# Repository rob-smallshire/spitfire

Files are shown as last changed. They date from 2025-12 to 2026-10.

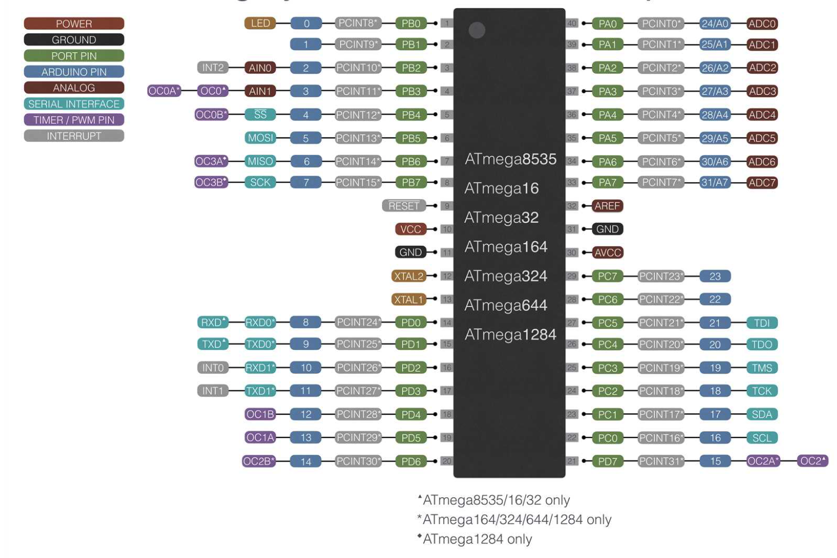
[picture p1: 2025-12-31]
docs/datasheets/atmega-1284p-pinout.png

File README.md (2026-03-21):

# SPItFIRE

**SPI + joystick FIRE button** - An analogue joystick and quadrature mouse adapter for the Acorn BBC Master Compact.

## Overview

The Acorn BBC Master Compact lacks the analogue-to-digital converter (ADC) hardware found in other BBC Micro models, making it incompatible with standard analogue joysticks. SPItFIRE bridges this gap by providing:

- **Analogue joystick support** via ADC sampling of potentiometer positions
- **Peripheral DE-9 port** for connecting a quadrature mouse (or other devices)
- **Keyboard matrix scanning** for joystick buttons

The system uses an ATMega1284p microcontroller as an SPI slave device. The BBC Master Compact's Mouse/Joystick port (an exposed 6522 VIA) communicates with the microcontroller via a bit-banged SPI protocol.

## Architecture

```
                               Host DE-9
┌─────────────────────┐         SPI          ┌──────────────────────┐
│  BBC Master Compact │◄────────────────────►│     ATMega1284p      │
│                     │   (bit-banged on     │                      │
│  6522 VIA Port      │    User VIA Port B)  │  ┌────────────────┐  │
└─────────────────────┘                      │  │ ADC: Joystick  │  │
                                             │  │ GPIO: Buttons  │  │
                                             │  │ GPIO: Mouse    │  │
                                             │  └────────────────┘  │
                                             └──────────────────────┘
                                                      │
                       ┌──────────────────────┬───────┴───────┐
                       ▼                      ▼               ▼
                 ┌──────────┐          ┌──────────┐   ┌──────────────┐
                 │ Joystick │          │  Keypad  │   │ Peripheral   │
                 │ (Analog) │          │  Matrix  │   │    DE-9      │
                 │  DA-15   │          │          │   │ Mouse/Serial │
                 └──────────┘          └──────────┘   └──────────────┘
```

## Repository Structure

```
spitfire/
├── firmware/           ATMega1284p C++ firmware (SPI slave)
│   ├── src/            Source files
│   ├── include/        Header files
│   ├── cmake/          CMake toolchain files
│   ├── CMakeLists.txt  Build configuration
│   └── CMakePresets.json
├── rom/                BBC Micro 6502 assembly ROM driver
│   └── src/            BeebAsm source files
├── hardware/           KiCAD hardware designs
│   └── spitfire/       Main schematic and PCB
└── docs/               Documentation
    └── protocol.md     SPI protocol specification
```

## Building

### Firmware (ATMega1284p)

Requirements:
- CMake 3.20+
- avr-gcc toolchain
- avrdude (for programming)

```bash
cd firmware
cmake --preset release
cmake --build --preset release
cmake --build --preset release --target upload
```

### ROM (BBC Micro)

Requirements:
- BeebAsm assembler

```bash
cd rom
make
```

## Hardware

The hardware design is created in KiCAD. See the `hardware/` directory for schematics and PCB layouts.

### Connectors

SPItFIRE has two DE-9 connectors:

- **Host DE-9**: Connects to BBC Master Compact's Mouse/Joystick port (exposes 6522 VIA). Carries SPI bus signals and device selection.
- **Peripheral DE-9**: Directly connects input devices to SPItFIRE. Directly accepts quadrature mice, switched joysticks, or serial devices. Connected to AVR Port D.

### Additional Connections

- **Joystick Inputs**: Two DA-15 ports for analogue joysticks (directly via ADC channels)

## Protocol

The BBC Micro bit-bangs an SPI protocol on the VIA port to:
- Configure the adapter
- Request joystick position data (X/Y axes)
- Request mouse velocity data
- Read button states

See [docs/protocol.md](docs/protocol.md) for the full protocol specification.

## License

This project is licensed under the GNU General Public License v3.0 - see the [LICENSE](LICENSE) file for details.

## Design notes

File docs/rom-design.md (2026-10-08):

# SPItFIRE ROM Design

This document describes the proposed architecture for the BBC Micro Sideways
ROM that drives the SPItFIRE adapter. It is a working proposal and will
evolve as we implement and learn.

## Goals

- Provide standard BBC Micro APIs (ADVAL, INKEY, OSWORD &40, *MOUSE, etc.)
  so existing software works without modification.
- Be modular: support optional features matching the hardware actually
  plugged into the SPItFIRE.
- Share a common SPI driver across all modules.
- Compatible with the BBC sideways ROM ecosystem and existing conventions.

## Architecture Overview

```
┌─────────────────────────────────────────┐
│           SPItFIRE ROM Image            │
├─────────────────────────────────────────┤
│  ROM Header (one per ROM)               │
│    - JMP to Service dispatcher          │
│    - Standard BBC Micro ROM type/title  │
│    - Copyright, version                 │
├─────────────────────────────────────────┤
│  Service Dispatcher                     │
│    - Offers each service call to each   │
│      enabled module in turn             │
│    - Standard claim/pass conventions    │
├─────────────────────────────────────────┤
│  Module: SPI Core (always present)      │
│    - Bit-bang SPI routines              │
│    - Turbo (shift register) routines    │
│    - 74HC138 device selection           │
│    - Shared zero-page workspace         │
├─────────────────────────────────────────┤
│  Module: Mouse (optional)               │
│    - Hooks BYTEV, EVENTV                │
│    - Uses SPI Core                      │
│    - Provides ADVAL 7-9, OSWORD &40     │
│    - *MOUSE [ON|OFF|TYPE]               │
├─────────────────────────────────────────┤
│  Module: Joystick (optional)            │
│    - Hooks BYTEV                        │
│    - Uses SPI Core                      │
│    - Provides ADVAL 1-4 (or extended)   │
├─────────────────────────────────────────┤
│  Module: RTC (optional)                 │
│    - Service call &08: OSWORD &0E/&0F   │
│    - So *TIME and TIME$ read the DS3234 │
└─────────────────────────────────────────┘
```

The SD card filing system is not part of this ROM: it is MMFS, built
with a SPItFIRE device driver, in a ROM of its own. See
[SD Card Filing System](#sd-card-filing-system-separate-mmfs-rom).

## Reference: JGH's Module System

J.G. Harston's relocatable module system at
[mdfs.net](https://mdfs.net/Software/BBC/Modules/) provides useful precedent:

- **MouseROM** - reference for mouse API conventions (we'll rewrite the
  hardware-facing end completely; the MOS-facing API is identical).
- **SoftRTC2** - reference for RTC integration with system clock.
- **SMLib** - relocatable module framework (we may adopt later, not
  required for first version).
- **MMFS** - existing MMC filing system. Standard MMFS ties SS to
  ground, so we added a SPItFIRE device driver to it (see below).

We should not be wilfully different on the MOS-facing side. Standard
APIs and command syntax should match the existing BBC ecosystem.

## Module: SPI Core

Always present. Provides shared low-level routines used by all other
modules.

### Responsibilities
- Initialise User VIA for SPI bit-bang and shift register modes
- Bit-bang SPI transfer routine (~4100 bytes/sec)
- Turbo SPI transfer routine using VIA shift register (~7400 bytes/sec)
- 74HC138 device selection (constants for each device assignment)
- Common workspace allocation

### Public Routines
| Routine | Inputs | Outputs | Description |
|---|---|---|---|
| `init_via` | - | - | One-time VIA setup |
| `select_device` | A=device | - | Set SCK to the device's idle level, then select it via 74HC138 |
| `deselect_device` | - | - | Deselect (Y7 = no device) |
| `spi_transfer` | A=byte | A=received | Bit-bang transfer |
| `spi_turbo_read` | - | A=received | Fast read using shift register |

### Per-device SPI mode
The 6522 shift register samples MISO on the rising edge of SCK (CB1), so
every device must present data that is stable at the rising edge:

| Device | SPI mode | SCK idle level when selected |
|---|---|---|
| SPItFIRE AVR | 0 | Low |
| DS3234 RTC | 3 (it picks CPOL from SCK at CS falling) | High |
| SD card | 3 (as MMFS) | High |

`select_device` must therefore set SCK to the device's idle level
*before* asserting chip select, and the transfer routines must keep that
idle level between bytes. Verified with SPIRTC on the Rev 1 board.

### Device Assignments
See [spi-interface.md](spi-interface.md) and
[peripheral-pinouts.md](peripheral-pinouts.md).

| Output | Device | Constant |
|---|---|---|
| Y0 | Unassigned (unconnected on Rev 1; spare header on Rev 2) | |
| Y1 | SPItFIRE AVR | `DEV_SPITFIRE` |
| Y2 | SD card (J4, Adafruit microSD breakout) | `DEV_SD` |
| Y3 | RTC (J5, SparkFun DeadOn DS3234) | `DEV_RTC` |
| Y4-Y6 | Unassigned (spare headers J6-J8) | |
| Y7 | None (deselect): the Compact's idle state, see [spi-interface.md](spi-interface.md) | `DEV_NONE` |

## The `*SPITFIRE` Command Namespace

Standard commands like `*MOUSE`, `*TIME`, `*DATE` are kept in their
established namespaces for ecosystem compatibility. SPItFIRE-specific
configuration and extensions live under a `*SPITFIRE` command with a
subcommand structure that mirrors the module hierarchy.

### Rationale
- Avoids polluting the global `*` command namespace
- Groups all SPItFIRE-specific functionality under one prefix
- The hierarchy maps naturally to the modular ROM design
- Tab-style discoverability via `*HELP SPITFIRE`

### Proposed Subcommand Structure
This is a working sketch, not a final design:

| Command | Description |
|---|---|
| `*SPITFIRE` | Show ROM version and active modules |
| `*SPITFIRE INFO` | Show hardware status, AVR firmware version, attached devices |
| `*SPITFIRE HELP [topic]` | Show help (optionally for a subsystem) |
| `*SPITFIRE MOUSE ON\|OFF` | Alias for `*MOUSE ON\|OFF` |
| `*SPITFIRE MOUSE TYPE AMX\|AMIGA\|ATARI` | Select pinout (AVR mode) |
| `*SPITFIRE MOUSE SENSITIVITY sx [,sy]` | Set per-axis sensitivity (2^sx GU/pulse) |
| `*SPITFIRE MOUSE INFO` | Report current state, pulse counts, mode |
| `*SPITFIRE JOYSTICK A 14B\|3B\|3B-TWIN\|...` | Configure joystick port A |
| `*SPITFIRE JOYSTICK B ...` | Configure joystick port B |
| `*SPITFIRE JOYSTICK INFO` | Report joystick state |
| `*SPITFIRE RTC INFO` | Show RTC status (oscillator stop flag, temperature, aging) |
| `*SPITFIRE SD INFO` | Show SD card status |

### Implementation Note
Each module registers its own `*SPITFIRE <name>` subcommand handler.
The top-level `*SPITFIRE` parser dispatches to the appropriate module
based on the first word after `*SPITFIRE`. A module's subcommand
handler need not be present if the module is excluded from the build.

## Module: Mouse

Replicates the JGH/AMX mouse API. Polls the SPItFIRE AVR via SPI on a
periodic timer event instead of using CB1/CB2 IRQs.

### MOS-facing API (drop-in compatible)
| Call | Description |
|---|---|
| `*MOUSE ON` | Enable mouse |
| `*MOUSE OFF` | Disable mouse |
| `*HELP MOUSE` | Show help text |
| `ADVAL(5)` | Mouse X boundary (max X) |
| `ADVAL(6)` | Mouse Y boundary (max Y) |
| `ADVAL(7)` | X position (graphics units, 0-1279) |
| `ADVAL(8)` | Y position (graphics units, 0-1023) |
| `ADVAL(9)` | Buttons - active HIGH (b0=Left, b1=Middle, b2=Right) |
| `INKEY-10` | Left button (-1 if pressed) |
| `INKEY-11` | Middle button |
| `INKEY-12` | Right button |
| `OSWORD &40` | Full mouse state to user buffer (see below) |

### OSWORD &40 buffer format
7 bytes returned at the address pointed to by XY:

| Offset | Content |
|---|---|
| +0 | LSB of X co-ordinate |
| +1 | MSB of X co-ordinate |
| +2 | LSB of Y co-ordinate |
| +3 | MSB of Y co-ordinate |
| +4 | Text X co-ordinate (0-19 / 0-39 / 0-79 depending on MODE) |
| +5 | Text Y co-ordinate (0-31) |
| +6 | Buttons - format `cme00000`, **active LOW** (bit reset = pressed) |

Note the dual button conventions:
- **ADVAL(9)**: active-high in bits 0-2, order Left/Middle/Right
- **OSWORD &40 byte 6**: active-low in bits 5-7, order Execute/Move/Cancel
  (= Left/Middle/Right) - this matches the raw IORB layout on a BBC/Master
  with buttons on PB5-PB7

### Coordinate Systems

The mouse driver returns positions in two coordinate systems:

| Coordinate | Units | Range | Origin |
|---|---|---|---|
| Graphics X | Graphics units (GU) | 0-1279 | Bottom-left |
| Graphics Y | Graphics units (GU) | 0-1023 | Bottom-left |
| Text X | Character cells | 0-19 (MODE 7), 0-39 (MODE 1/4/5), 0-79 (MODE 0/3/6) | Top-left |
| Text Y | Character cells | 0-24 (MODE 3/6), 0-31 (others) | Top-left |

Important conventions inherited from BBC Micro / Acorn MOS:

- **Graphics origin is bottom-left**: Y=0 at the bottom of the screen,
  Y increases upward. This is opposite to many other systems (notably
  modern displays, X11, Windows, etc. which place origin at top-left).
- **Text origin is top-left**: text Y=0 at the top, increasing downward.
- **Mouse Y increment direction**: when the mouse is moved upward (away
  from the user), graphics Y increases, matching BBC graphics convention.
- The graphics coordinate system is independent of screen MODE - it is
  always 1280x1024 GU regardless of the actual pixel resolution. The MOS
  scales graphics commands appropriately.

The text coordinate ranges depend on the current screen MODE:

| MODE | Text Width | Text Height |
|---|---|---|
| 0 | 80 columns | 32 rows |
| 1 | 40 columns | 32 rows |
| 2 | 20 columns | 32 rows |
| 3 | 80 columns | 25 rows |
| 4 | 40 columns | 32 rows |
| 5 | 20 columns | 32 rows |
| 6 | 40 columns | 25 rows |
| 7 | 40 columns | 25 rows (teletext) |

### Standard commands not directly implemented
The original AMX ROM provided pointer/icon/window helper commands and
a `*SENSITIVITY sx [,sy]` command. We do not reimplement these in
`*MOUSE` namespace; instead:
- Pointer/icon/window helpers are out of scope (they are GUI helpers,
  not core mouse driver functionality)
- Sensitivity adjustment is exposed via `*SPITFIRE MOUSE SENSITIVITY`
  (see SPItFIRE namespace below)

References:
- [BeebWiki OSBYTE &80](https://beebwiki.mdfs.net/OSBYTE_%2680) - ADVAL details
- AMX Mouse User Guide: `docs/datasheets/AMX_MouseUG.pdf` chapter 5
- ADVAL(9) bit ordering: BeebWiki says "b0=Left, b1=Middle, b2=Right";
  JGH's `%rml` notation describes the same bits (binary digit positions:
  r is highest, m middle, l lowest = b2,b1,b0).
- BeebWiki notes: "Most mouse drivers do not implement calls 5, 6 and 9."
  We should implement all of them for completeness since the AVR provides
  the data cheaply.

### SPItFIRE-specific extensions
SPItFIRE-specific configuration is exposed via the `*SPITFIRE` namespace
(see above) rather than extending the standard `*MOUSE` command:

| Command | Description |
|---|---|
| `*SPITFIRE MOUSE TYPE AMX` | Select AMX/Compact pinout (AVR mode 0xF1) |
| `*SPITFIRE MOUSE TYPE AMIGA` | Select Amiga pinout (AVR mode 0xF2) |
| `*SPITFIRE MOUSE TYPE ATARI` | Select Atari pinout (AVR mode 0xF3) |
| `*SPITFIRE MOUSE SENSITIVITY sx [,sy]` | Set per-axis sensitivity (2^sx GU/pulse) |
| `*SPITFIRE MOUSE INFO` | Report state, mode, pulse counts |

### Workspace (drop-in compatible with JGH)
| Address | Use |
|---|-----|
| `&DA5` | Status (b7=enabled, b3-b0=type/speed) |
| `&DA6-&DA9` | Position (X.lo, X.hi, Y.lo, Y.hi) |
| `&DAA` | Flag |
| `&D9B-&D9D` | Saved BYTEV (3 bytes) |
| `&DAE-&DB0` | Extended BYTEV (XBYTEV) |

### Polling Mechanism
- Hook EVENTV
- Use Event 4 (vsync) for 50 Hz polling, OR
- Use Event 5 with OSWORD &03 interval timer for 100 Hz
- 50 Hz vsync is simpler and likely sufficient
- Each event: select SPItFIRE, send 0x30/0x31/0x32 commands, deselect,
  accumulate dX/dY into position, store buttons

### Button Format Conversion
The AVR returns buttons as `b0=L, b1=R, b2=M`. ADVAL(9) requires `%rml`
which is `b0=L, b1=M, b2=R`. The driver swaps bits 1 and 2.

### Position Bounds
- Initial position: X=&280 (640), Y=&200 (512)
- Increment of 4 graphics units per pulse (matches BBC convention)
- Bound to screen extent via OSBYTE &A0 (read VDU vars)

## Module: Joystick

Provides analogue joystick support via SPItFIRE.

### MOS-facing API
| Call | Description |
|---|---|
| `ADVAL(1)` | Channel 0 X (joystick A) |
| `ADVAL(2)` | Channel 0 Y |
| `ADVAL(3)` | Channel 1 X (joystick B) |
| `ADVAL(4)` | Channel 1 Y |
| `OSBYTE &80` with X=0 | Last channel converted |
| Various INKEY values | Fire buttons |

### SPItFIRE-specific commands
TBD - configuration of joystick types (3B Single, 3B Twin, 14B keypad, etc.)
matching the existing AVR firmware test interface.

### Polling Mechanism
- ADC values change slowly (analogue position)
- Could poll on demand (each ADVAL call) or periodically
- Periodic polling at 25 Hz via vsync should be sufficient

## Module: RTC

Makes the DS3234 on J5 (decoder output Y3, `DEV_RTC`) the machine's
clock, so `*TIME`, BASIC's `TIME$` and anything else using OSWORD &0E
(read clock) and &0F (write clock) see real time. The Master 128 had a
clock; the Compact's was removed to save cost, and MOS 5.10 only returns
a fixed default.

### Findings on the Compact
Probed with TIMEPROBE (`beeb/spitest/src/timeprobe.asm`), which calls
OSWORD &0E with all ROMs, with every ROM hidden, and with each ROM on its
own. Results on our Compact (MOS 5.10, ANFS 4.25 in slot 3):

| Call | All ROMs (ANFS answers) | MOS only |
|---|---|---|
| &0E,0 string | ` ,71 Oct 1994.23:25:49` | `Fri,31 Dec 1999.23:59:59` |
| &0E,1 BCD | `94 10 71 00 23 25 49` | `99 12 31 06 23 59 59` |
| &0E,2 of `26 10 07 04 12 34 56` | - | `Wed,07 Oct 1926.12:34:56` |
| &0E,2 of `26 10 07 00 12 34 56` | - | ` ,07 Oct 1926.12:34:56` |

- **MOS 5.10 offers OSWORD &0E to sideways ROMs** with service call &08
  (unrecognised OSWORD). ANFS 4.25 answers subcalls 0 and 1 by asking the
  Econet file server. With no ROM answering, the MOS returns its default,
  Fri 31 Dec 1999 23:59:59. (The Master 128 MOS handles these calls
  itself and never offers them to ROMs; a Master add-on would have to
  claim WORDV instead.)
- **MOS subcall 2 always prints the century as 19**, so 2026 comes out
  as 1926. A weekday of 0 prints as three spaces. The MOS offers subcall
  2 to ROMs first, though: with the SPItFIRE ROM loaded, TIMEPROBE's
  all-ROMs conversion of year &26 gives 2026.
- Every string is 25 bytes, `Ddd,dd Mon yyyy.hh:mm:ss` plus CR.
- **ANFS 4.25 mis-decodes file server dates after 1996.** The server puts
  the high year bits in bits 5-7 of the day byte, and ANFS passes the
  whole byte on as the date. `71` with year `94` decodes as
  day = 71 AND 31 = 7, year = (71 AND &E0)/2 + 94 + 1900 = 2026: the
  correct date, 7 Oct 2026. The file server is right; ANFS is wrong.
  ANFS also returns weekday 0 ("unknown"). This is what `*TIME` showed
  before SPItFIRE.

### How the module hooks in
- **Service call &08.** On entry the OSWORD number is at &EF and the
  parameter block address at &F0/&F1. Handle OSWORD &0E and &0F, return
  A=0 to claim, and preserve X and Y. Anything not handled returns with
  A unchanged, so other ROMs (ANFS especially) still see it.
- **ROM slot above ANFS.** Service calls are offered from the highest slot
  down, so the SPItFIRE ROM must sit in a higher slot than ANFS (slot 3
  on our Compact) to answer before it.
- **If no DS3234 is fitted, or the clock is not valid**, pass the call
  on, so the machine falls back to ANFS or the MOS default.
  - *Presence* (all calls): MISO floats when nothing drives it (Rev 1
    has no pull-up; see Rev 2 erratum 2 in
    [rev1-bringup.md](rev1-bringup.md)), so a read alone cannot show that
    a DS3234 answered. The module writes the complement of the SRAM
    address register (18h, no side effects) and reads it back, then
    restores it. A floating line cannot echo the value.
  - *Validity* (reads only): the oscillator stop flag must be clear and
    every time field valid BCD within its range. The ranges also cover
    the bits that always read 0, and reject 12-hour mode. Writes do not
    require a valid stored time, so `*TIME` can always repair the clock.

### Calls to implement

| Call | Data | Notes |
|---|---|---|
| &0E,0 | Return `Ddd,dd Mon yyyy.hh:mm:ss` + CR (25 bytes) | Build the string ourselves with the real century; do not use MOS subcall 2 |
| &0E,1 | Return 7 BCD bytes: year, month, date, weekday, hours, minutes, seconds | Weekday &01-&07 = Sun-Sat, as SPISETTIME writes it to the DS3234 |
| &0E,2 | Convert 7 BCD bytes at XY+1 to a string | MOS 5.10 offers it to ROMs before converting it itself, so claiming it fixes the century for every caller. Year &00-&79 = 20xx, &80-&99 = 19xx |
| &0F,8 | `hh:mm:ss` | Set the time, leave the date |
| &0F,15 | `Ddd,dd Mon yyyy` | Set the date, leave the time |
| &0F,24 | `Ddd,dd Mon yyyy.hh:mm:ss` | Set both |

Leave alone: &0E subcalls 3 and 4, which ANFS uses for the file server's
time (and other ROMs use inconsistently), and every other subcall or
length. The string field positions are fixed: programs parse `TIME$`.

### Conventions (from the Stardot discussions)
- **OSWORD calls never raise errors.** Invalid OSWORD &0F data is
  ignored (or passed on). Errors belong to `*` commands.
- **&A8-&AF belong to `*` commands.** An OSWORD handler that uses them
  as workspace must save and restore them (e.g. on the stack).
- **Return the real four-digit year** in subcall 0. Copying the
  Master's 19xx is not required by the specification.
- The 6502's V flag is not valid in decimal mode, which matters for any
  BCD arithmetic (e.g. a future timezone offset).

### Setting the clock
`*TIME <string>` and `TIME$=` set the clock through OSWORD &0F, so
nothing extra is needed beyond the &0F handler: verified on the Compact,
where MOS 5.10's `*TIME` passes its argument to OSWORD &0F. Any of the
three forms (time, date, or both) works from either.

The handler ignores the weekday name and computes the weekday from the
date (Sakamoto's method, reduced to 8 bits for 2000-2199). It accepts
years 2000-2199, the range of the DS3234's century bit, checks the date
against the length of the month (2100 is not a leap year), and passes
anything invalid on. A successful write clears the oscillator stop flag.

### Possible later extensions
Time & Config defines further subcalls: &0E,5 for century and timezone,
&0E,6 for when the clock was last set, &0F lengths for synchronising to
the second and adjusting drift. None is a settled standard; leave them
out of the first version.

### Not to be confused with the system clock
OSWORD 1/2 (`TIME` in BASIC) is a centisecond counter, unrelated to the
calendar clock; the earlier idea of writing the RTC into &028D-&028F is
wrong.

## SD Card Filing System (separate MMFS ROM)

**Decision:** the SD card is served by MMFS in its own ROM, not by a
module of the SPItFIRE ROM. MMFS gets a SPItFIRE device driver and
nothing else, so the change stays small enough to offer upstream.

- Fork: <https://github.com/rob-smallshire/MMFS>, branch `spitfire`
  (upstream <https://github.com/hoglet67/MMFS>). Local clone at
  `~/Code/MMFS` with `origin` = the fork, `upstream` = hoglet67.
- Driver: `MMC_Spitfire.asm`, MMFS device `S`. Based on the non-turbo
  User Port driver (`MMC_UserPort.asm`, device `U`).
- Build: the Master build (`top_MAMMFS.asm`) is the one for the Compact.
  MMFS2 (FAT32 card with `.ssd`/`.dsd` files) is the variant in use.
- Tested on the Rev 1 board: `*DCAT`, `*DIN` and running games from a
  FAT32 SDHC card. Writes are not yet tested on hardware.

### How the driver differs from the User Port driver
- PB0-PB4 are outputs, and every write to IORB carries the SD card's
  select code (Y2, `&08`), so the card stays selected throughout a
  transaction.
- The bit-banged byte write keeps PB2-PB4 constant. The User Port
  version lets unsent data bits ripple across PB2-PB7, which on our
  board would switch the decoder between devices mid-byte. The rewrite
  is about 1.6x slower, but writes are only bit-banged commands and data
  blocks; bulk reads use shift register mode 2 and run at the original
  speed.
- `MMC_DEVICE_RESET` (called from `MMC_BEGIN1` at the start of every
  transaction) raises SCK with no device selected, then selects the card
  (SPI mode 3).
- `MMC_DEVICE_DESELECT` selects Y7 (no device) and sends 8 clocks so the card
  releases MISO. It is called from `ResetLEDS`, which MMFS calls at the
  end of every card operation and when reporting any error, and from
  `MMC_END`. `MMC_END` alone was not enough: `MMC_BEGIN`/`MMC_END`
  bracket a zero page save, not a card operation (`MMC_BEGIN2` calls
  both at once, and the reads follow), so the card was left selected
  after booting with MMFS2 active and after `*DCAT`. Verified on the
  Compact: the decoder now rests on no device and the SD card's LED is off
  except while loading.
- The TurboMMC mode 6 write path is not used: it relies on external
  buffers switched by PB2-PB4, which on our board are decoder inputs.

### ROM space
The Master MMFS2 build leaves about 3.4 KB free, which could only just
hold the rest of the SPItFIRE modules (estimated 2.3-3.7 KB) with no
margin. Keeping them separate also keeps the MMFS fork upstreamable.
The cost is a second ROM slot; at least one Compact socket takes a 32K
ROM spanning two 16K sideways slots, so this is not a constraint in
practice.

### Bus access between the two ROMs (to be designed)
The mouse (and possibly joystick) module will poll the AVR from an
interrupt, and that poll must not disturb an MMFS transaction in
progress. Points to settle:

- A "bus busy" flag at an address both ROMs agree on. The
  interrupt-time poll must *skip* when the flag is set; it must never
  wait, because MMFS cannot proceed until the interrupt returns.
- Where MMFS sets and clears it: not `MMC_BEGIN1`/`MMC_END`, which do
  not bracket card operations (see above). `SetLEDS` and `ResetLEDS`
  bracket nearly all of them, and `ResetLEDS` also runs on every error
  report, so the flag would not be left set by a BRK. Exceptions to
  cover: `MMC_GetCIDCRC` (card ID check) reads the card without
  `SetLEDS`.
- Outside a transaction, a poll changes PB2-PB4, the SCK idle level and
  possibly the shift register mode. Either the poll restores what it
  found, or MMFS reselects at the start of every transaction. It already
  does the latter in `MMC_DEVICE_RESET`.

## Build/Configuration System

### Directory Structure
```
beeb/spitfire-rom/
├── src/
│   ├── header.asm          # ROM header, service dispatcher
│   ├── spi_core.asm        # Shared SPI driver
│   ├── mod_mouse.asm       # Mouse module
│   ├── mod_joystick.asm    # Joystick module
│   ├── mod_rtc.asm         # RTC module
│   └── workspace.asm       # Shared workspace allocation
├── configs/
│   ├── full.asm            # All modules
│   ├── mouse_only.asm      # SPI core + mouse only
│   ├── input.asm           # SPI core + mouse + joystick
│   └── clock.asm           # SPI core + RTC
└── Makefile                # Build rule per config
```

### Configuration Files
Each `configs/<name>.asm` is a thin wrapper:
```asm
ROM_TITLE = "SPItFIRE Mouse"
ROM_VERSION = "0.01"

INCLUDE "../src/header.asm"
INCLUDE "../src/workspace.asm"
INCLUDE "../src/spi_core.asm"
INCLUDE "../src/mod_mouse.asm"
INCLUDE "../src/footer.asm"

SAVE "SPITFIRE", start, end
```

### Module Conventions
Each module file should:
- Define its own labels in a unique prefix (e.g. `mouse_init`)
- Provide a service entry point `<module>_service`
- Declare its workspace requirements
- Document its dependencies (e.g. requires SPI Core)

### Service Dispatch Pattern
Header's service dispatcher offers the call to each module in turn:
```asm
.Service
    JSR mouse_service
    BEQ exit_service           ; A=0 means claimed
    JSR joystick_service
    BEQ exit_service
    JSR rtc_service
    BEQ exit_service
    ; ... unclaimed, exit normally
.exit_service
    RTS
```

Modules return claim status in A:
- A=0: claimed (stop dispatch)
- A unchanged: not handled (continue dispatch)

## Open Questions

1. **Single ROM vs multiple ROMs?**
   - Single 16K ROM with all modules: consumes one bank slot, simple to load
   - Multiple ROMs: better separation, but uses multiple bank slots
   - **Decision:** Two ROMs. The SPItFIRE ROM holds the SPI core, mouse,
     joystick and RTC modules, configurable at build time. The SD card
     filing system is a separate MMFS ROM (see
     [SD Card Filing System](#sd-card-filing-system-separate-mmfs-rom)).

2. **Relocation support?**
   - JGH's SMLib provides full relocatability
   - Not needed if we always build for &8000
   - **Initial preference:** Build for fixed address, add relocation later if needed

3. **Module enable/disable at runtime?**
   - User could disable modules with `*CONFIG`-style commands
   - More flexible but more complex
   - **Initial preference:** Build-time configuration only

4. **MMFS_Spitfire vs adopting an existing variant?**
   - Could fork existing MMFS source
   - Or implement minimal MMC layer for our hardware
   - **Decision:** Forked MMFS and added a device driver
     (`MMC_Spitfire.asm`, device `S`); working on the Rev 1 board

5. **RTC chip selection?**
   - DS3231 is popular and accurate (built-in TCXO)
   - DS3234 is the SPI variant of DS3231
   - **Decision:** DS3234 (SparkFun DeadOn breakout on J5); proven on the
     Rev 1 board by SPIRTC and SPISETTIME

## Implementation Plan (Proposed Order)

The RTC hardware is proven and its MOS interface is now understood, so
the RTC module comes first and brings the ROM skeleton with it:

1. **RTC module** - ROM header, service dispatcher, SPI core, OSWORD &0E
   and &0F (done, working on the Compact)
2. **Mouse module** - first input feature, hardware proven
3. **Joystick module** - reuse AVR firmware joystick code path
4. **Single-config build first** - all modules in one ROM, configurable later
5. **SD card** - done, as a separate MMFS ROM; still to do is the bus
   access protocol shared with the mouse module

## References

- [BeebWiki OSBYTE &80](https://beebwiki.mdfs.net/OSBYTE_%2680) - ADVAL details
- AMX Mouse User Guide: `docs/datasheets/AMX_MouseUG.pdf`
  ([source](https://chrisacorns.computinghistory.org.uk/docs/AMX/AMX_MouseUG.pdf))
- [JGH's relocatable modules](https://mdfs.net/Software/BBC/Modules/)
- [BeebWiki OSWORD &0E](https://beebwiki.mdfs.net/OSWORD_%260E) and
  [OSWORD &0F](https://beebwiki.mdfs.net/OSWORD_%260F) - clock calls,
  per-MOS behaviour, the ANFS date fix
- Stardot: [OSWORD 14 & 15 numbers](https://stardot.org.uk/forums/viewtopic.php?t=28743)
  and [Time & Config](https://stardot.org.uk/forums/viewtopic.php?t=30412)
  (Barney Hilken's RTC board; ROM source at
  <https://codeberg.org/Barneyntd/Time-Config.>)
- [JGH's MouseROM source](https://mdfs.net/Software/CommandSrc/Mouse/ROMMouse.src)
- [MDFS BBC Mouse documentation](https://mdfs.net/Info/Comp/BBC/Mouse/)
- Internal: [protocol.md](protocol.md) - SPI command set
- Internal: [spi-interface.md](spi-interface.md) - hardware layer
- Internal: [peripheral-pinouts.md](peripheral-pinouts.md) - device pinouts
- Internal: [mouse-trackball-peripheral.md](mouse-trackball-peripheral.md) - mouse details

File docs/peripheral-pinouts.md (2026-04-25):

# Peripheral DE-9 Pinouts

The SPItFIRE has a **male DE-9 Peripheral port** to support connection of the following devices:

* Master Compact Mouse (e.g. Prodest PC128S DigiMouse) - three button
* Master Compact/Atari Switched Joystick
* Amiga Mouse - three button
* Atari ST Mouse - two button (some three-button variants exist)
* Microsoft Bus Mouse - passive, unpowered (e.g. green-eyed mouse)
* TTL Serial port (e.g. StarTech IC232TTL TTL-to-RS232 adapter)

Port D of the AVR is connected to the Peripheral DE-9 and configured under software control to support these different device classes.

## AVR Port D Mapping

| DE-9 Pin | AVR Pin | Function | Notes |
|---|---|---|---|
| 1 | PD0 | RXD0 / GPIO | UART RX for IC232TTL; GPIO for mice/joystick |
| 2 | PD1 | TXD0 / GPIO | UART TX for IC232TTL; GPIO for mice/joystick |
| 3 | PD2 | GPIO | |
| 4 | PD3 | GPIO | |
| 5 | PD4 | GPIO | |
| 6 | PD5 | GPIO | |
| 7 | — | +5V | Hardwired, no AVR pin |
| 8 | — | GND | Hardwired, no AVR pin |
| 9 | PD6 | GPIO | |
| LED | PD7 | GPIO | Status LED, active on prototype |

The UART pins (PD0/PD1) are constrained by AVR hardware to map to Peripheral DE-9 pins 1/2, which conveniently aligns with the IC232TTL's RXD/TXD pins. For mouse and joystick modes, PD0/PD1 are reconfigured as standard GPIO inputs.

## Pinout Table

| Pin | AVR Pin | Compact Mouse | Joystick | Amiga Mouse | Atari Mouse | MS Bus Mouse | IC232TTL |
|-----|---|---|---|---|---|---|---|
| 1 | PD0 | XB | Up | YB | XB | NC | RXD |
| 2 | PD1 | Right Btn | Down | XA | XA | XA | TXD |
| 3 | PD2 | Middle Btn | Left | YA | YA | XB | NC |
| 4 | PD3 | YB | Right | XB | YB | YA | NC |
| 5 | PD4 | XA | NC | Middle Btn  | NC | YB | 0V |
| 6 | PD5 | Left Btn | Fire | Left Btn | Left Btn | Button 1 | NC* |
| 7 | — | +5V | NC | +5V | +5V | (B3)* | NC |
| 8 | — | 0V | 0V | 0V | 0V | Button 2 | NC |
| 9 | PD6 | YA | NC | Right Btn | Right Btn | 0V | NC |

**Notes:**
- NC* = Pin 6 on IC232TTL is a 5V *output* (device powered from RS232 side). Configure as Hi-Z.
- (B3)* = Bus mouse interface cards support Button 3 on pin 7, but SPItFIRE hardwires pin 7 to +5V for mouse/joystick compatibility. Third button not supported on bus mouse.
- Quadrature signals use standard notation: XA/XB for horizontal axis, YA/YB for vertical axis.
- Acorn documentation uses alternate naming: Xaxis=XA, Xdir=XB, Yaxis=YA, Ydir=YB.
- All button signals are active-low (directly connect to ground when pressed).

## Quadrature Signal Convention

All quadrature mice use the same encoding, only the pinout differs:

```
Movement right/down: (0,0) → (1,0) → (1,1) → (0,1) → (0,0)
Movement left/up:    (0,0) → (0,1) → (1,1) → (1,0) → (0,0)

When A leads B by 90°: positive direction (right/down)
When B leads A by 90°: negative direction (left/up)
```

## Gender Changer Requirements

The SPItFIRE Peripheral port is **male DE-9**. Standard mice and joysticks have female DE-9 plugs and connect directly. The following devices have male DE-9 plugs and require a **female-to-female gender changer**:

| Device | Connector | Gender Changer Required  |
|---|---|---|
| Compact Mouse | Female DE-9 | No - direct connection |
| Amiga Mouse | Female DE-9 | No - direct connection |
| Atari Mouse | Female DE-9 | No - direct connection |
| Atari/Compact Joystick | Female DE-9 | No - direct connection |
| Microsoft Bus Mouse | Male DE-9 | **Yes - F-F adapter** |
| StarTech IC232TTL | Male DE-9 | **Yes - F-F adapter** |

## Device-Specific Notes

### Master Compact Mouse

The Compact mouse pinout matches the BBC Master Compact's Mouse/Joystick port directly. The quadrature signals are on pins 1, 4, 5, 9 with buttons on pins 2, 3, 6.

Reference: [mdfs.net BBC Mouse](https://mdfs.net/Info/Comp/BBC/Mouse/)

### Amiga Mouse

The Amiga uses V-pulse/VQ-pulse (vertical) and H-pulse/HQ-pulse (horizontal) naming:
- V-pulse = YB, VQ-pulse = YA
- H-pulse = XA, HQ-pulse = XB

Pin 5 supports middle button/scroll wheel on three-button mice.

Reference: [AllPinouts Amiga Mouse](https://allpinouts.org/pinouts/connectors/input_device/mouse-joystick-amiga-9-pin/)

### Atari ST Mouse

The Atari ST pinout differs from Amiga - pins 1 and 4 carry different signals. Some third-party mice have an Amiga/Atari switch that swaps these signals.

The right mouse button (pin 9) on port 0 is shared with the fire button of port 1 on the Atari ST.

Reference: [old.pinouts.ru Atari ST](https://old.pinouts.ru/InputCables/atari_st_joystick_pinout.shtml)

### Microsoft Bus Mouse (Green-Eyed Mouse)

The original 1983 Microsoft mouse is entirely passive and requires no power supply. All six sensors operate as active-low switches. Pins 1 and 7 are physically not fitted on the original mouse connector, preventing accidental connection to RS-232 serial ports.

While the bus mouse ISA interface card supports a third button on pin 7, SPItFIRE hardwires this pin to +5V for compatibility with other mice. This means only two buttons are supported on bus mice - acceptable since the original green-eyed mouse has only two buttons anyway.

Reference: [What is a Bus Mouse?](https://blog.smallshire.no/blog/what-is-a-bus-mouse/)

### StarTech IC232TTL

TTL-level serial adapter. The device is powered from the RS232 side, with pin 6 being a 5V output. SPItFIRE should configure pin 6 as Hi-Z input to avoid conflict.

Reference: [IC232TTL Manual (PDF)](https://sgcdn.startech.com/005329/media/sets/IC232TTL_manual/IC232TTL_manual.pdf)

## Amiga vs Atari Comparison

The key difference between Amiga and Atari mice is the quadrature signal routing:

| Pin | Amiga | Atari |
|-----|---|---|
| 1 | YB | XB |
| 2 | XA | XA |
| 3 | YA | YA |
| 4 | XB | YB |

Pins 1 and 4 differ. This is why mice with an "Amiga/Atari" switch exist.

**Note on MDFS pinout labelling:** The Amiga and Atari mouse pinouts shown on
[mdfs.net](https://mdfs.net/Info/Comp/BBC/Mouse/) have the Y-axis signal
designations (YA/YB) reversed with respect to native Amiga and Atari
conventions. The MDFS assignments are correct for BBC Micro use - the Y-axis
labels are swapped to make the mouse coordinate system handedness match BBC
Micro software conventions. The X-axis labels are not affected. The pinout
table in this document uses the native Amiga/Atari conventions, not the
MDFS/BBC-adapted labelling.

# BBC Micro User Port Connector

The SPItFIRE unit is intended for the Master Compact mouse/joystick port. This machine
lacks the traditional User Port sported by all other models of BBC Micro and Master.
The User Port exposed all 10 data signals of the User VIA of the BBC Micro, CB1, CB2 and PB0 to PB7
inclusive. The user port was used for many peripherals, perhaps most notably the Marconi RB2
trackerball, the AMX Mouse and other mouses such as the Nidd Valley DigiMouse. The various mouses
seem to follow a common pinout, but the Marconi Trackerball is different.

The User Port used a 20 way 2x10 pin header connector with male on the machine and a female IDC
connector on the peripheral cable.

## Mouse and Trackerball User Port Pinouts

| Pin | VIA | Mouse | Trackerball |
|-----|-----|---|---|
|  2  | CB1 |  XA | XA |
|  4  | CB2 |  YA | YB |
|  6  | PB0 |  XB | LB |
|  8  | PB1 | | MB |
| 10  | PB2 |  YB | RB |
| 12  | PB3 | | XB |
| 14  | PB4 | | YA |
| 16  | PB5 |  LB | |
| 18  | PB6 |  MB | |
| 20  | PB7 |  RB | |

The Marconi RB2 documentation uses X1/X2/Y1/Y2 notation (X1=XA, X2=XB, Y1=YA, Y2=YB).
Note that CB2 carries YA for mice but YB for the trackerball - the devices are not identical.

References:
- Mouse: [mdfs.net BBC Mouse](https://mdfs.net/Info/Comp/BBC/Mouse/)
- Trackerball: [Marconi RB2 User Guide (PDF)](https://www.domesday86.com/wp-content/uploads/2017/01/Marconi-RB2-User-Guide-BBC-Model-B.pdf)

These two devices cover all 10 signal pins of the user port, so we don't have
enough available signals on AVR Port D (7 bits, one reserved for status LED)
to individually service all ten User Port pins.

## User Port to DE-9 Adapter

A small adapter PCB can convert User Port mice and trackerballs for use with
SPItFIRE's Peripheral DE-9. The adapter uses the **Master Compact Mouse pinout**
on the DE-9 end, which gives it dual-purpose capability:

- **AMX Mouse (and compatibles):** Works with SPItFIRE (Compact Mouse mode)
  **and** directly with the Master Compact's mouse port (no SPItFIRE required).
- **Marconi RB2 Trackerball:** Works with SPItFIRE only (requires dedicated
  trackerball firmware mode). Not directly compatible with the Master Compact
  due to pinout differences.

The adapter merges signals from both device types onto seven DE-9 signal pins,
since only one device is connected at a time.

### Adapter Connectors

- **Input:** Female 20-way (2x10) IDC shrouded header (accepts User Port cable)
- **Output:** Male DE-9 (plugs into SPItFIRE Peripheral DE-9 or Master Compact
  Mouse/Joystick port)

### Adapter Wiring

| IDC Pin | VIA | Mouse | Trackerball | DE-9 Pin | Compact Signal | AVR Pin |
|---|-----|---|---|---|---|---|
|  2 | CB1 |  XA | XA | 5 | XA (Xaxis) | PD4 |
|  4 | CB2 |  YA | YB | 9 | YA (Yaxis) | PD6 |
|  6 | PB0 |  XB | LB | 1 | XB (Xdir) | PD0 |
|  8 | PB1 | | MB | 3 | Middle Btn | PD2 |
| 10 | PB2 |  YB | RB | 4 | YB (Ydir) | PD3 |
| 12 | PB3 | | XB | 6 | Left Btn | PD5 |
| 14 | PB4 | | YA | 2 | Right Btn | PD1 |
| 16 | PB5 |  LB | | 6 | Left Btn | PD5 |
| 18 | PB6 |  MB | | 3 | Middle Btn | PD2 |
| 20 | PB7 |  RB | | 2 | Right Btn | PD1 |
| 1/3 | | +5V | +5V | 7 | +5V | — |
| odd | | GND | GND | 8 | 0V | — |

Merged connections (wire both IDC pins to the same DE-9 pin):
- DE-9 pin 2: IDC pins 14 + 20
- DE-9 pin 3: IDC pins 8 + 18
- DE-9 pin 6: IDC pins 12 + 16

This works because the unused pins on each device are physically unconnected
inside the peripheral, so no signal conflict occurs.

### Why AMX Mouse Works Directly with the Master Compact

The AMX Mouse signals map exactly to the Master Compact Mouse pinout through
the adapter. The trackerball-only IDC pins (8, 12, 14) are not connected inside
the mouse, so they float harmlessly on the merged DE-9 lines.

### Trackerball via SPItFIRE

When a Marconi RB2 trackerball is connected via the adapter, SPItFIRE sees:

| DE-9 Pin | AVR Pin | Trackerball Signal |
|---|---|---|
| 1 | PD0 | LB |
| 2 | PD1 | YA |
| 3 | PD2 | MB |
| 4 | PD3 | RB |
| 5 | PD4 | XA |
| 6 | PD5 | XB |
| 9 | PD6 | YB |

This requires a dedicated "User Port Trackerball" firmware mode. No additional
mode is needed for the AMX Mouse since it appears identical to a Compact Mouse.

### Firmware Modes Summary

| Mode | Device | Source |
|---|---|---|
| Compact Mouse | Master Compact Mouse (DE-9) | Direct |
| Compact Mouse | AMX Mouse (via adapter) | Via adapter |
| Amiga Mouse | Amiga Mouse (DE-9) | Direct |
| Atari Mouse | Atari ST Mouse (DE-9) | Direct |
| Bus Mouse | Microsoft Bus Mouse (DE-9)  | Direct |
| Joystick | Switched joystick (DE-9) | Direct |
| User Port Trackerball | Marconi RB2 (via adapter) | Via adapter |
| Serial | IC232TTL (DE-9) | Direct |

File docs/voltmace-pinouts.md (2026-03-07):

| DA-15 pin | Acorn | Delta 3b Single  | Delta 3b Twin | Delta 14b |  SPItfire   |
|           |       |                  |               |           |  A   |  B   |
|-----------|-------|------------------|---------------|-----------|-------------|
| 1         | +5V   |                  |               |           |
| 2         | 0V    |                  |               | COL2      | PC0  | PC1  |
| 3         | 0V    | COL1             | ROW3_RIGHT    | COL1      | PB2  | PB3  |
| 4         | CH3   | Y_RIGHT (Y_LEFT) | Y_RIGHT       | ROW0      | PA6  | PA7  | 
| 5         | AGND  |                  | AGND_RIGHT    | COL0      | PB0  | PB1  |
| 6         | 0V    |                  | ROW3_LEFT     | ROW1      | PC2  | PC3  |
| 7         | CH1   | Y_LEFT (Y_RIGHT) | Y_LEFT        | Y         | PA2  | PA3  |
| 8         | AGND  | AGND             | AGND_LEFT     | AGND      | AGND | AGND |
| 9         | LPSTB |                  |               |           |      |      |
| 10        | PB1   | ROW3             | COL1_RIGHT    | ROW2      | PC4  | PC5  |
| 11        | VREF  |                  | VREF_RIGHT    |           | VREF | VREF |
| 12        | CH2   | X_RIGHT (X_LEFT) | X_RIGHT       |           | PA4  | PA5  |
| 13        | PB0   | ROW4             | COL1_LEFT     | ROW3      | PC6  | PC7  |
| 14        | VREF  | VREF             | VREF_LEFT     | VREF      | VREF | VREF |
| 15        | CH0   | X_LEFT (X_RIGHT) | X_LEFT        | X         | PA0  | PA1  |

DA-15 pin : The pin number on the DA-15 analogue port or joystick connector
Acorn     : The Acorn designation according to Acorn Application Note 021
Delta 3B single: The designation for a Delta 3B Single joystick
Delta 3B twin: The designation for a Delta 3B Twin joystick
Delta 14B: The designation for a Delta 14B joystick
Spitfire A and B: How the pins of the two DA-15 ports on the SPItFIRE module map
  to the digital I/O ports of the ATMega1284p microcontroller

Note that Voltmace repurpose some of the pins such a Acorn's AGND when the
Delta 14B joystick is used with the Delta 14B/1 control box which places
additional logic between the joystick and the analogue user ports
of the BBC Micro. This is rather clever, as these pins have no ill effects
when such a joystick is connected directly to the BBC Micro analogue port,
other than some buttons becoming undetectable.

## Fire Button Wiring

The standard BBC Micro DA-15 analogue port provides only two digital inputs
for fire buttons: PB0 (DA-15 pin 13) and PB1 (DA-15 pin 10).

### Delta 3B Twin

The 3B Twin has two handsets, each with three physical fire buttons.
All three buttons on each handset are wired in parallel:
- Left handset buttons → PB0 (DA-15 pin 13) → PC6 (Port A) / PC7 (Port B)
- Right handset buttons → PB1 (DA-15 pin 10) → PC4 (Port A) / PC5 (Port B)

This gives 2 logical buttons (one per handset), active-low with internal pull-ups.

Note: Internally, the 3B Twin wires buttons with rows grounded and columns as
signals (opposite to the 3B Single). This difference is handled by the joystick
PCB wiring to the DA-15 connector, so the software interface is identical.

### Delta 3B Single

The 3B Single is an unusual design: a single handset with potentiometers wired
to both X/Y pairs, allowing it to serve as either player's joystick in a
turn-based two-player game.

It has three physical buttons in two groups:
- 2 buttons → PB0 (left fire, DA-15 pin 13) → PC6 (Port A) / PC7 (Port B)
- 1 button → PB1 (right fire, DA-15 pin 10) → PC4 (Port A) / PC5 (Port B)

This gives 2 logical buttons, active-low with internal pull-ups.

### Delta 14B

The 14B has a 3×4 keypad matrix (12 buttons) which requires the full matrix
scanning implemented in keypad.cpp. The original Delta 14B/1 interface box
handled this scanning and connected to both the BBC Micro analogue port and
User Port. SPItFIRE replaces the 14B/1 interface with AVR-based scanning.

#### Keypad Matrix Layout

```
ROW3: [9]  [10] [11]   (top row)
ROW2: [6]  [7]  [8]
ROW1: [3]  [4]  [5]
ROW0: [0]  [1]  [2]    (bottom row)
      COL0 COL1 COL2
```

Button number = ROW × 3 + COL

Two additional physical buttons are wired in parallel with button 10,
giving 14 physical buttons but only 12 logical buttons.

#### Scan Result Encoding

The keypad scan returns a 12-bit value where bit N corresponds to button N.
A bit value of 0 indicates the button is pressed (active-low).

| Button | Bit | Hex (pressed) | Position |
|---|-----|---|---|
| 0 | 0 | FFE | Bottom-left |
| 1 | 1 | FFD | Bottom-mid  |
| 2 | 2 | FFB | Bottom-right|
| 3 | 3 | FF7 | Row 1 left  |
| 4 | 4 | FEF | Row 1 mid |
| 5 | 5 | FDF | Row 1 right |
| 6 | 6 | FBF | Row 2 left  |
| 7 | 7 | F7F | Row 2 mid |
| 8 | 8 | EFF | Row 2 right |
| 9 | 9 | DFF | Top-left |
| 10 | 10  | BFF | Top-mid |
| 11 | 11  | 7FF | Top-right |

With no buttons pressed, the scan returns FFF.

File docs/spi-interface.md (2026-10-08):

# SPI Interface Design Document

## Overview

SPItFIRE uses SPI to communicate between the BBC Master Compact and an ATmega1284p microcontroller. The BBC acts as SPI master, bit-banging the protocol on its User VIA. The AVR acts as SPI slave using its hardware SPI peripheral.

The design uses CB1 wired to PB1 externally to enable both bit-banged and shift-register-accelerated transfers (following the MMFS approach). A 74HC138 3-to-8 decoder expands three VIA output pins into seven independent chip select lines, allowing up to seven SPI devices on the bus.

## Connector Terminology

SPItFIRE has two DE-9 connectors with distinct roles:

| Connector | Description |
|---|---|
| **Host DE-9** | Connects to the BBC Master Compact Mouse/Joystick port. Carries SPI signals (MOSI, MISO, SCK) and device selection via the 74HC138 decoder. The BBC is the SPI master. |
| **Peripheral DE-9** | Directly connects input devices to SPItFIRE. Directly accepts quadrature mice, switched joysticks, or other peripherals. Connected to AVR Port D. |

This naming convention is used consistently throughout the documentation:
- "Host" = toward the BBC Master Compact (SPI master side)
- "Peripheral" = toward input devices (directly connected to AVR)

## Host DE-9 Pinout

The Host DE-9 connects to the BBC Master Compact's Mouse/Joystick port, which exposes User VIA pins:

| DE-9 Pin | VIA Signal | SPI Function | Direction |
|---|---|---|---|
| 1 | PB3 | Decoder A1 | Output |
| 2 | PB2 | Decoder A0 | Output |
| 3 | PB1 | SCK | Output |
| 4 | PB4 | Decoder A2 | Output |
| 5 | CB1 | SCK | Input (wire to pin 3) |
| 6 | PB0 | MOSI | Output |
| 7 | +5V | Power | - |
| 8 | 0V | GND | - |
| 9 | CB2 | MISO | Input |

## SPI Signal Assignment

Following MMFS conventions for MOSI, SCK, and MISO:

| VIA Pin | SPI Function | Notes |
|---|---|---|
| PB0 | MOSI | Data to slave (same as MMFS) |
| PB1 | SCK | Clock, wired to CB1 (same as MMFS) |
| PB2 | Decoder A0 | Device select bit 0 |
| PB3 | Decoder A1 | Device select bit 1 |
| PB4 | Decoder A2 | Device select bit 2 |
| CB1 | SCK | Wired to PB1 for shift register clock |
| CB2 | MISO | Data from slave (same as MMFS) |

## Multi-Device SPI Bus

A 74HC138 3-to-8 decoder expands three VIA pins into seven chip select lines. The decoder outputs are active-low, directly compatible with SPI SS requirements.

### 74HC138 Connections

```
                              74HC138
                            ┌────┴────┐
                        A0 ─┤1      16├─ VCC
                        A1 ─┤2      15├─ Y0 (unconnected on Rev 1)
                        A2 ─┤3      14├─ Y1 → [1kΩ] → AVR PB4 (SS)
                       ~G0 ─┤4      13├─ Y2 → J4 SD card
                       ~G1 ─┤5      12├─ Y3 → J5 RTC
                        G2 ─┤6      11├─ Y4 → J6 (spare)
       (no device) J9 ← Y7 ─┤7      10├─ Y5 → J7 (spare)
                       GND ─┤8       9├─ Y6 → J8 (spare)
                            └─────────┘
```

### Decoder Enable Configuration

The enable pins are hard-wired so one output is always active:
- G2 (pin 6) = VCC (active high enable)
- ~G0 (pin 4) = GND (active low enable)
- ~G1 (pin 5) = GND (active low enable)

### Full System Wiring

```
Host DE-9                   74HC138                 Devices
─────────                   ───────                 ───────
Pin 2 (PB2) ─────────────────→ A0
Pin 1 (PB3) ─────────────────→ A1
Pin 4 (PB4) ─────────────────→ A2
                               Y0 ─── (no connection on Rev 1)
                               Y1 ───[1kΩ]──→ AVR PB4 (SS)
                               Y2 ─────────→ J4 SD card
                               Y3 ─────────→ J5 RTC
                               Y4 ─────────→ J6 (spare)
                               Y5 ─────────→ J7 (spare)
                               Y6 ─────────→ J8 (spare)
                               Y7 ─────────→ J9: no device (keep empty)

Pin 6 (PB0) ─────────[1kΩ]───────────────→ AVR PB5 (MOSI)
Pin 3 (PB1) ──┬──────[1kΩ]───────────────→ AVR PB7 (SCK)
Pin 5 (CB1) ──┘ (wire together)
Pin 9 (CB2) ←────────[1kΩ]─────────────── AVR PB6 (MISO)
Pin 8 (0V)  ───────────────────────────── GND (common)
```

### Device Selection

Write a 3-bit device number to PB4:PB3:PB2 to select a device:

| A2 (PB4) | A1 (PB3) | A0 (PB2) | Value | Active Output | Rev 1 | Rev 2 (proposed) |
|---|---|---|---|---|---|---|
| 0 | 0 | 0 | 0 | Y0 | Unconnected | Spare header (J9) |
| 0 | 0 | 1 | 1 | Y1 | SPItFIRE AVR | SPItFIRE AVR |
| 0 | 1 | 0 | 2 | Y2 | SD card (J4) | SD card |
| 0 | 1 | 1 | 3 | Y3 | RTC (J5) | RTC |
| 1 | 0 | 0 | 4 | Y4 | Spare header J6 | J6 |
| 1 | 0 | 1 | 5 | Y5 | Spare header J7 | J7 |
| 1 | 1 | 0 | 6 | Y6 | Spare header J8 | J8 |
| 1 | 1 | 1 | 7 | Y7 | **No device** (J9, keep empty) | **No device** (unconnected) |

**"No device" is Y7, all ones.** The Compact pulls PB2-PB4 up (about
4.1k each) whenever port B is not driving them, at power-up, after reset
and before any SPItFIRE code runs, so the decoder rests on Y7 anyway.
Software deselects to the same code, so the bus looks the same whether
or not SPItFIRE code has run. Y0 cannot be used as "no device": see Rev 2
erratum 3 in [rev1-bringup.md](rev1-bringup.md). On Rev 1, J9 (Y7) must
stay empty.

### Software Interface

Device selection uses pre-shifted constants for efficiency (no runtime shifting):

```asm
; Port B bit assignments
SEL_A0   = %00000100        ; PB2 - decoder A0
SEL_A1   = %00001000        ; PB3 - decoder A1
SEL_A2   = %00010000        ; PB4 - decoder A2
SEL_MASK = %00011100        ; All decoder bits (PB2-PB4)

; Device constants (pre-shifted to PB2-4 position)
DEV_NONE     = %00011100    ; Y7 - no device selected (A2=1, A1=1, A0=1)
DEV_SPITFIRE = %00000100    ; Y1 - SPItFIRE (A0=1)
DEV_SD       = %00001000    ; Y2 - SD card (A1=1)
DEV_RTC      = %00001100    ; Y3 - RTC (A1=1, A0=1)
DEV_4        = %00010000    ; Y4 - spare (A2=1)
DEV_5        = %00010100    ; Y5 - spare (A2=1, A0=1)
DEV_6        = %00011000    ; Y6 - spare (A2=1, A1=1)

; Mask for clearing decoder bits
NOT_SEL  = %11100011        ; Clear PB2, PB3, PB4

; Select SPItFIRE
    LDA IORB
    AND #NOT_SEL            ; Clear decoder bits
    ORA #DEV_SPITFIRE       ; Set device 1
    STA IORB

; Deselect (idle)
    LDA IORB
    ORA #DEV_NONE           ; Set decoder bits (Y7, no device)
    STA IORB
```

**Note:** This interface differs from standard MMFS, which ties SS to ground (always selected). SD card support uses a custom MMFS device driver (`MMC_Spitfire.asm`) that controls device selection via the decoder; see [rom-design.md](rom-design.md).

## SPItFIRE As-Built Wiring

Connection from Host DE-9 (directly via female breakout board) through 74HC138 decoder
to ATmega1284p. A straight-through DE-9 cable connects to the Master Compact.

```
Host DE-9                   74HC138             ATmega1284p
─────────                   ───────             ───────────
Pin 2 (PB2) ─────────────────→ A0
Pin 1 (PB3) ─────────────────→ A1
Pin 4 (PB4) ─────────────────→ A2
                               Y1 ────[1kΩ]────→ PB4 (SS)
Pin 3 (PB1/SCK)  ──┬─────────[1kΩ]─────────────→ PB7 (SCK)
Pin 5 (CB1)      ──┘ (wire together)
Pin 6 (PB0/MOSI) ────────────[1kΩ]─────────────→ PB5 (MOSI)
Pin 9 (CB2/MISO) ←───────────[1kΩ]───────────── PB6 (MISO)
Pin 8 (GND)      ──────────────────────────────── GND

74HC138 power and enable:
  Pin 16 (VCC) ── +5V
  Pin 8 (GND)  ── GND
  Pin 6 (G2)   ── +5V (enable)
  Pin 4 (~G0)  ── GND (enable)
  Pin 5 (~G1)  ── GND (enable)
```

| Connection | From | To | Notes |
|---|---|-----|---|
| Decoder A0 | Host DE-9 pin 2 (PB2) | 74HC138 pin 1 | Device select bit 0 |
| Decoder A1 | Host DE-9 pin 1 (PB3) | 74HC138 pin 2 | Device select bit 1 |
| Decoder A2 | Host DE-9 pin 4 (PB4) | 74HC138 pin 3 | Device select bit 2 |
| SS | 74HC138 Y1 (pin 14) | AVR PB4 | Via 1kΩ resistor |
| SCK | Host DE-9 pin 3 (PB1) | AVR PB7 | Via 1kΩ resistor |
| CB1 | Host DE-9 pin 5 | Host DE-9 pin 3 | Wire together |
| MOSI | Host DE-9 pin 6 (PB0) | AVR PB5 | Via 1kΩ resistor |
| MISO | AVR PB6 | Host DE-9 pin 9 (CB2) | Via 1kΩ resistor |
| GND | Host DE-9 pin 8 | Common | All grounds connected |

Host DE-9 pin 7 (+5V) is currently unused.

## Series Resistors

1kΩ series resistors serve two purposes:

**ISP programming compatibility (MOSI, SCK, SS):** The BBC VIA (via the decoder)
and ISP programmer both drive these lines to the AVR. The resistors allow the
programmer to override the BBC's signals during programming.

**Protection (MISO):** Although only the AVR drives MISO, a series resistor is
included for general protection.

```
ISP Programmer               ATmega1284p
──────────────               ───────────
MOSI ──────────────────────→ PB5 (direct, overrides BBC via 1kΩ)
MISO ←──────────────────────── PB6 (direct)
SCK  ──────────────────────→ PB7 (direct, overrides BBC via 1kΩ)
RESET ─────────────────────→ RESET
```

Future SPI devices on other decoder outputs (Y2-Y7) would also benefit from
series resistors if they share pins with an ISP header.

## SPI Protocol Parameters

| Parameter | Value |
|---|---|
| Mode | SPI Mode 0 (CPOL=0, CPHA=0) |
| Bit Order | MSB first |
| Clock Speed | ~10-50 kHz (bit-bang) or faster (shift register) |
| SS Polarity | Active low |

### Mode 0 Timing

```
        ┌───┐   ┌───┐   ┌───┐   ┌───┐
SCK  ───┘   └───┘   └───┘   └───┘   └───
        ↑       ↑       ↑       ↑
      sample  sample  sample  sample

Data changes on falling edge, sampled on rising edge.
```

## VIA Initialization Requirements

Correct VIA initialization is critical for reliable SPI operation. The following
registers must be explicitly set to known values before any SPI transfers.

### CB1/CB2 Interrupts Must Be Disabled

**This is the most critical step.** Because CB1 is wired to PB1 (SCK), every
falling edge of the SPI clock triggers CB1. If the OS has left CB1 interrupts
enabled in the IER, this causes an IRQ on every clock pulse.

With 8 clock pulses per byte, a 256-byte transfer generates 2048 interrupts.
Each interrupt handler invocation takes thousands of cycles, resulting in
transfer speeds of ~6 bytes/second instead of the expected ~4000 bytes/second.

```asm
IER = &FE6E         ; User VIA Interrupt Enable Register

; Disable CB1 and CB2 interrupts
; Bit 7 = 0 means "clear the specified bits"
; Bits 4,3 = CB1, CB2
LDA #%00011000
STA IER
```

### ACR and PCR Must Be Set to Known Values

Previous code may have left the Auxiliary Control Register (ACR) or Peripheral
Control Register (PCR) in unexpected states. Do not use AND/OR to modify these
registers; set them to absolute values.

```asm
ACR = &FE6B         ; Auxiliary Control Register
PCR = &FE6C         ; Peripheral Control Register

; Set PCR: CB2 input, CB1 negative edge
LDA #%00000000
STA PCR

; Set ACR: Shift register disabled
LDA #%00000000
STA ACR
```

### Complete VIA Initialization Sequence

```asm
; Port B bit assignments
MOSI     = %00000001    ; PB0
SCK      = %00000010    ; PB1
SEL_A0   = %00000100    ; PB2 - decoder A0
SEL_A1   = %00001000    ; PB3 - decoder A1
SEL_A2   = %00010000    ; PB4 - decoder A2
SEL_MASK = %00011100    ; All decoder bits

.init_via
    ; 1. Disable CB1/CB2 interrupts FIRST
    LDA #%00011000
    STA IER

    ; 2. Set PCR to known state
    LDA #%00000000
    STA PCR

    ; 3. Set ACR to known state (SR disabled)
    LDA #%00000000
    STA ACR

    ; 4. Set port direction (PB0=MOSI, PB1=SCK, PB2-4=decoder as outputs)
    LDA DDRB
    ORA #MOSI OR SCK OR SEL_MASK
    STA DDRB

    ; 5. Set idle state: no device (Y7), SCK low (CPOL=0), MOSI high
    LDA IORB
    AND #NOT_SCK        ; SCK low
    ORA #MOSI OR SEL_MASK   ; MOSI high, no device (Y7)
    STA IORB

    RTS
```

## Transfer Modes

### Bit-Bang Mode (Simple)

The simplest approach: toggle PB0 (MOSI) and PB1 (SCK) directly, shifting out
one bit at a time. Read CB2 for MISO if needed (or use shift register to
capture incoming data).

```asm
; Full bit-bang SPI transfer
; Send byte in A, returns received byte in A
.spi_transfer
    STA spi_temp

    ; Clear shift register
    LDA SR

    ; Start with SCK low
    LDA IORB
    AND #NOT_SCK
    STA IORB

    LDX #8
.spi_bit
    ; Shift out next bit
    LDA spi_temp
    ASL A
    STA spi_temp

    ; Set MOSI based on carry
    LDA IORB
    AND #%11111110      ; Clear MOSI
    BCC mosi_low
    ORA #MOSI
.mosi_low
    STA IORB            ; MOSI set, SCK still low

    ; Rising edge - slave samples MOSI, outputs MISO
    ORA #SCK
    STA IORB

    NOP                 ; Setup time
    NOP

    ; Falling edge - shift register captures MISO via CB1
    AND #NOT_SCK
    STA IORB

    DEX
    BNE spi_bit

    LDA SR              ; Read received byte
    RTS
```

Measured performance: **~4,100 bytes/second** (65536 transfers in 15.9 seconds).

### Shift Register Mode (Turbo Reads)

For read-heavy operations (like polling joystick/mouse), the shift register
provides significant acceleration. This leverages VIA shift register **mode 3**
(shift in under external CB1 control).

Because CB1 is wired to PB1, toggling SCK automatically clocks data into the
shift register. MISO (on CB2) is captured on each falling edge of CB1/SCK.

**Key insight:** When reading (sending 0xFF), MOSI stays high for all 8 bits.
We can set MOSI once and then just toggle SCK, eliminating per-bit branching.

#### VIA Configuration for Turbo Mode

```asm
SR_IN_CB1 = %00001100   ; ACR mode 3: Shift in under CB1 control

.init_via_turbo
    ; Disable CB1/CB2 interrupts
    LDA #%00011000
    STA IER

    ; CB2 input, CB1 negative edge
    LDA #%00000000
    STA PCR

    ; Enable shift register mode 3
    LDA #SR_IN_CB1
    STA ACR

    ; Set port direction
    LDA DDRB
    ORA #MOSI OR SCK OR SS
    STA DDRB

    ; Idle state: SS high, SCK low, MOSI high
    LDA IORB
    ORA #MOSI OR SS
    AND #NOT_SCK
    STA IORB

    RTS
```

#### Optimized Turbo Read Routine

```asm
; Fast read-only transfer using shift register
; Sends 0xFF (MOSI stays high), returns received byte in A
; Much faster than full spi_transfer - no per-bit MOSI handling
.spi_read_byte
    LDA SR              ; Clear shift register

    ; MOSI high (sending 0xFF) - set once, not per-bit
    LDA IORB
    ORA #MOSI
    AND #NOT_SCK        ; Ensure SCK low
    STA IORB

    ; Just toggle SCK 8 times - SR captures MISO on falling edges
    LDX #8
.read_clock
    LDA IORB
    ORA #SCK            ; Rising edge
    STA IORB
    AND #NOT_SCK        ; Falling edge - SR captures
    STA IORB
    DEX
    BNE read_clock

    LDA SR              ; Read received byte
    RTS
```

Measured performance: **~7,400 bytes/second** (65536 transfers in 8.9 seconds).

### Performance Comparison

| Mode | Technique | Rate | Relative |
|---|---|---|---|
| Bit-bang | Full spi_transfer | 4,124 bytes/sec | 1.0x |
| Turbo | spi_read_byte (SR mode 3) | 7,371 bytes/sec | 1.79x |

The turbo mode is **79% faster** for read operations. The gains come from:
1. No per-bit MOSI handling (just 8 clock toggles)
2. No conditional branching in the inner loop
3. Shift register captures data automatically

For the joystick/mouse interface, which is read-biased, turbo mode is the
clear choice. Writes (if needed) can fall back to bit-bang mode.

## Clock Speed Considerations

- BBC Micro runs at 2 MHz
- AVR runs at 18.432 MHz
- Measured bit-bang throughput: ~4,100 bytes/sec (~33 kHz bit rate)
- Measured turbo read throughput: ~7,400 bytes/sec (~59 kHz bit rate)
- Joystick updates at 50 Hz need only ~4-6 bytes per frame (~300 bytes/sec)
- Plenty of bandwidth for joystick, mouse, and SD card access

## ATmega1284p SPI Slave

| AVR Pin | Function | Direction |
|---|---|---|
| PB4 | SS | Input (active low) |
| PB5 | MOSI | Input |
| PB6 | MISO | Output |
| PB7 | SCK | Input |

Hardware SPI configured as slave, mode 0, MSB first.

## Alternative Approach: Time&Config

The Time&Config project (RTC and FRAM interface) also uses the User VIA for serial
communication but takes a different approach:

| VIA Pin | Time&Config Function |
|---|---|
| PB1 | Clock line (input with pullup, pulsed during cleanup) |
| PB5 | RTC chip select (active low) |
| PB6 | RTC alarm signal (input) |
| PB7 | FRAM chip select (active low) |
| CB1 | Shift register clock (external from RTC) |
| CB2 | Shift register data (bidirectional) |

Key differences from MMFS/SPItFIRE:

1. **External clock source**: The RTC chip provides clock pulses at 4096 Hz to CB1,
   rather than the BBC generating clock via PB1.

2. **No PB1-CB1 wiring**: Since the clock comes from the RTC, no external wire
   between PB1 and CB1 is needed.

3. **Different chip selects**: Uses PB5/PB7 instead of PB2/PB3/PB4.

4. **VIA shift register modes**: Uses Timer 2-controlled output (mode 6) and
   external clock input (mode 2), rather than the MMFS approach of software-
   clocked shifts.

The designs use non-overlapping chip select lines, so they could potentially
coexist. However, the PB1-CB1 wire required for MMFS/SPItFIRE would conflict
with Time&Config's expectation of external clock input on CB1.

## References

- [MMFS GitHub - Hardware Wiki](https://github.com/hoglet67/MMFS/wiki/Hardware)
- [MMFS Stardot Forum](https://www.stardot.org.uk/forums/viewtopic.php?t=30037)
- MMFS uses identical CB1/PB1 wiring for shift register acceleration
- [Time&Config - Codeberg](https://codeberg.org/Barneyntd/Time-Config.)

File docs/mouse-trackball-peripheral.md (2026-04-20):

# Mouse and Trackball Peripheral Design

## Overview

SPItFIRE reads quadrature mouse and trackball signals on AVR Port D, decodes
them into movement deltas, and reports the data over SPI to the BBC Micro.
This document describes the firmware architecture, SPI protocol, and BBC-side
test program.

## Architecture

```
Mouse/Trackball                 ATMega1284p                BBC Master Compact
───────────────                 ───────────                ────────────────────
  Quadrature     ──► Port D ──► Pin-Change ISR             Centisecond timer
  XA, XB,            (PD0-6)    ├─ remap[PIND]             ├─ SPI poll (100 Hz)
  YA, YB                       ├─ dx/dy lookup             │  ├─ CMD 0x30 → dX
  Buttons                      ├─ accumulate dx/dy         │  ├─ CMD 0x31 → dY
                               └─ read buttons             │  └─ CMD 0x32 → btns
                                        │                  ├─ accumulate totals
                               SPI Slave Main Loop         └─ display (10 Hz)
                                ├─ poll SPIF
                                ├─ clamp & drain accum
                                └─ return response
```

## Pin Remapping Architecture

Different mouse types use different signal-to-pin assignments on the Peripheral
DE-9. See [peripheral-pinouts.md](peripheral-pinouts.md) for full pinout tables.

### Remap Table Concept

Rather than testing individual pins in the ISR, a 128-byte lookup table converts
the raw PIND value directly into a packed 4-bit nibble:

```
Packed nibble: bit 0 = XA, bit 1 = XB, bit 2 = YA, bit 3 = YB
```

Each mouse type has its own remap table stored in flash (PROGMEM). The active
table is copied to SRAM for fast ISR access. Switching mouse type is a one-time
`memcpy_P()` of 128 bytes.

### Supported Modes

| Mode | XA | XB | YA | YB | Left | Right | Middle |
|---|----|----|----|----|---|---|---|
| Compact Mouse | PD4 | PD0 | PD6 | PD3 | PD5 | PD1 | PD2 |
| Amiga Mouse | PD1 | PD3 | PD2 | PD0 | PD5 | PD6 | PD4 |
| Atari Mouse | PD1 | PD0 | PD2 | PD3 | PD5 | PD6 | n/a |
| Bus Mouse | PD1 | PD2 | PD3 | PD4 | PD5 | n/a | n/a |
| Trackerball (adapter) | PD4 | PD5 | PD1 | PD6 | PD0 | PD3 | PD2 |

### Button Remap Tables

A separate 128-byte SRAM table maps PIND to a packed button byte
(bit 0=Left, bit 1=Right, bit 2=Middle, 1=pressed). Button pins are
active-low. Each mode has its own button table in PROGMEM.

### Table Generation

Tables are generated by `firmware/tools/gen_mouse_tables.py` and written to
`firmware/src/mouse_tables.inc`. This avoids error-prone manual computation
of 128-entry tables for each pinout.

## Quadrature Decoding

### State Machine

Each axis uses two signals (A and B) in Gray code:

```
Forward:  00 → 01 → 11 → 10 → 00  (A leads B by 90 degrees)
Reverse:  00 → 10 → 11 → 01 → 00  (B leads A by 90 degrees)
```

### Lookup Table Decode

Two universal 256-byte tables (`dx_table`, `dy_table`) in PROGMEM decode
both axes simultaneously. The index is `(prev_state << 4) | curr_state`
where each state is the 4-bit packed nibble from the remap table.

The 4x4 decode table per axis (numerical index order):

```
         curr: 00  01  10  11
prev 00:    0  +1  -1   0
     01:   -1   0   0  +1
     10:   +1   0   0  -1
     11:    0  -1  +1   0
```

Note: the columns and rows must be in numerical order (00, 01, 10, 11), not
Gray code order (00, 01, 11, 10), since the table is indexed numerically
by `(prev << 2) | curr`.

Invalid transitions (skipped states) return 0, providing natural debouncing.

### ISR Implementation

```cpp
ISR(PCINT3_vect) {
    uint8_t curr = remap[PIND & 0x7F];     // SRAM lookup: pins → nibble
    uint8_t idx = (prev_state << 4) | curr;
    dx_accum += (int8_t)pgm_read_byte(&dx_table_ptr[idx]);  // PROGMEM
    dy_accum += (int8_t)pgm_read_byte(&dy_table_ptr[idx]);  // PROGMEM
    prev_state = curr;
}
```

Buttons are read directly from PIND in the SPI command handler, not in the ISR.

**Important:** Port D on the ATMega1284P uses PCINT24-PCINT31, which is the
**PCINT3** group (PCMSK3/PCIE3/PCINT3_vect), NOT PCINT2 as one might assume
from the port letter. The mapping is:

| PCINT Group | Register | Vector | Port |
|---|---|---|---|
| PCINT0 | PCMSK0 | PCINT0_vect | Port B |
| PCINT1 | PCMSK1 | PCINT1_vect | Port C |
| PCINT2 | PCMSK2 | PCINT2_vect | Port A |
| PCINT3 | PCMSK3 | PCINT3_vect | Port D |

At 18.432 MHz, the ISR executes in approximately 2-3 us.

## Accumulator Model (Drain-on-Read)

### Concept

The AVR maintains 16-bit signed accumulators (`dx_accum`, `dy_accum`) that
are continuously updated by the ISR. When the BBC polls via SPI, the AVR:

1. Clamps the accumulator to [-127, +127]
2. Returns the clamped value as an int8
3. Subtracts the returned value from the accumulator

This means large movements are spread across consecutive polls:

```
Example: dx_accum = 300
  Poll 1: return +127, remaining = 173
  Poll 2: return +127, remaining = 46
  Poll 3: return +46,  remaining = 0
```

### Atomicity

The clamp-and-drain operation disables interrupts briefly to prevent the ISR
from modifying the accumulator mid-operation:

```cpp
cli();
int16_t val = dx_accum;
int8_t out = clamp(val, -127, 127);
dx_accum -= out;
sei();
```

### Why Not Velocity?

Serial mice established that **deltas** (not velocity) are the correct
abstraction. Velocity would require time normalisation and the host would
need to integrate anyway. Deltas decouple the AVR's continuous sampling from
the BBC's polling rate.

## SPI Protocol

Uses existing commands from [protocol.md](protocol.md):

| Command | Code | Response | Description |
|---|---|---|---|
| MOUSE_X | 0x30 | int8 | Clamped dX, drains accumulator |
| MOUSE_Y | 0x31 | int8 | Clamped dY, drains accumulator |
| MOUSE_BTN | 0x32 | uint8 | Button state (bit0=L, bit1=R, bit2=M) |
| MODE_AMX | 0xF1 | 0x01 | Switch to AMX/Compact pinout |
| MODE_AMIGA | 0xF2 | 0x02 | Switch to Amiga pinout |
| MODE_ATARI | 0xF3 | 0x03 | Switch to Atari pinout |

Mode switching loads the appropriate remap and button tables from flash to
SRAM and reconfigures the PCINT3 mask for the new quadrature pin assignments.
Accumulators are reset on mode change.

### Transaction Sequence

Each command requires two SPI byte transfers:

```
BBC sends command byte  → AVR reads command, prepares response, loads SPDR
BBC sends dummy (0x00)  → response clocked out to BBC
```

The BBC deselects (sets decoder to device 0) between commands.

A full mouse poll requires 3 commands = 6 SPI bytes. At ~4100 bytes/sec
bit-bang rate, this takes ~1.5 ms per poll. At 100 Hz polling, total SPI
bandwidth is ~600 bytes/sec, well within capacity.

## BBC Micro Test Program (SPIMOUSE)

### Polling Rate

100 Hz, synchronised to the MOS centisecond clock via OSWORD 1. The program
spins on the low byte of the 5-byte timer until it changes.

### Display Rate

10 Hz (every 10th poll). Uses VDU 31,X,Y to position the cursor for in-place
updates in MODE 7. No scrolling.

### Display Layout

```
SPItFIRE Mouse Test

dX=+03  dY=-01

X=04D2  Y=0567

Buttons: L - M
```

### Accumulation

The BBC maintains 16-bit signed totals, adding the sign-extended 8-bit deltas:

```
total_x (16-bit) += sign_extend(mouse_dx)
total_y (16-bit) += sign_extend(mouse_dy)
```

## Memory Budget

### AVR Flash

| Item | Size |
|---|---|
| 5 remap tables (PROGMEM) | 640 B |
| 5 button tables (PROGMEM) | 640 B |
| dx_table + dy_table (PROGMEM) | 512 B |
| Code | ~300 B |
| **Total** | **~2100 B** (1.6% of 128 KB) |

### AVR SRAM

| Item | Size |
|---|---|
| Active remap table | 128 B |
| Active button table | 128 B |
| Accumulators + state | 6 B |
| **Total** | **~262 B** (1.6% of 16 KB) |

## Building

### AVR Firmware

```bash
cd firmware
cmake --preset release
cmake --build --preset release --target spimouse
cmake --build --preset release --target upload_spimouse
```

### BBC Test Program

```bash
cd beeb/spitest
make SPIMOUSE
```

Load the resulting `build/SPIMOUSE` file onto the BBC Micro.

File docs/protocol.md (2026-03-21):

# SPItFIRE SPI Protocol Specification

This document describes the SPI communication protocol between the BBC Master Compact and the SPItFIRE adapter.

## Overview

The BBC Master Compact connects to SPItFIRE via the **Host DE-9** connector, which exposes the 6522 VIA. The host software bit-bangs an SPI protocol on the VIA output lines to communicate with the ATMega1284p, which operates as an SPI slave.

See [spi-interface.md](spi-interface.md) for connector terminology and physical layer details.

## Physical Layer

### Pin Assignments

| VIA Pin | Signal | Direction | Description |
|---|---|---|---|
| PBx | SCLK | Host→Device | SPI Clock |
| PBx | MOSI | Host→Device | Master Out, Slave In |
| PBx | MISO | Device→Host | Master In, Slave Out |
| PBx | CS | Host→Device | Chip Select (active low) |

*TODO: Define exact VIA pin assignments based on hardware design*

### SPI Configuration

- **Mode**: SPI Mode 0 (CPOL=0, CPHA=0)
- **Bit Order**: MSB first
- **Clock Speed**: Limited by VIA bit-banging (typically < 100 kHz)

## Protocol Layer

### Command Format

Each transaction begins with a command byte sent by the host:

```
┌─────────────────────────────────────────┐
│ Bit 7-4: Command   │ Bit 3-0: Params   │
└─────────────────────────────────────────┘
```

### Commands

We need much more than the following, but this gives a flavour.

| Command | Code | Description | Response Bytes |
|---|---|---|---|
| NOP | 0x00 | No operation | 0 |
| STATUS  | 0x10 | Get device status | 1 |
| JOY_X | 0x20 | Get joystick X position | 1 |
| JOY_Y | 0x21 | Get joystick Y position | 1 |
| JOY_BTN | 0x22 | Get joystick buttons | 1 |
| MOUSE_X | 0x30 | Get mouse X velocity | 1 (signed) |
| MOUSE_Y | 0x31 | Get mouse Y velocity | 1 (signed) |
| MOUSE_BTN | 0x32 | Get mouse buttons | 1 |
| CONFIG  | 0xF0 | Configuration command | varies |

### Joystick Data Format

Joystick position values are 8-bit unsigned (0-255):
- 0x00: Minimum position (left/up)
- 0x80: Centre position
- 0xFF: Maximum position (right/down)

### Mouse Data Format

Mouse velocity values are 8-bit signed (-128 to +127):
- Positive X: rightward movement
- Positive Y: downward movement

Button bytes use bit flags:
- Bit 0: Left button (1 = pressed)
- Bit 1: Right button (1 = pressed)
- Bit 2: Middle button (1 = pressed)

## Timing

*TODO: Define timing requirements*

## Error Handling

*TODO: Define error conditions and recovery*

## Example Transactions

### Read Joystick X Position

```
Host:  CS=0, send 0x20
Host:  receive 1 byte (position)
Host:  CS=1
```

### Read Mouse Velocity

```
Host:  CS=0, send 0x30
Host:  receive 1 byte (X velocity, signed)
Host:  CS=1
Host:  CS=0, send 0x31
Host:  receive 1 byte (Y velocity, signed)
Host:  CS=1
```

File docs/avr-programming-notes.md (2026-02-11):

# AVR Programming Notes

This document tracks fuse settings, programming parameters, and configuration changes for the ATMega1284p-PU.

## Hardware Configuration

- **MCU**: ATMega1284p-PU (40-pin DIP)
- **Target Clock**: 18.432 MHz external crystal
- **Load Capacitors**: 15 pF (22 pF failed on breadboard)
- **Programmer**: USBasp v1.04
- **Power**: External 5V (tested also with programmer power)

## Successful Programming Parameters

```bash
avrdude -c usbasp -p m1284p -B 125kHz
```

- SCK frequency: 93750 Hz
- Device signature: 1E 97 05 (ATmega1284P)

## Fuse Settings

### Current (Factory Default)

| Fuse  | Value | Description |
|---|---|---|
| lfuse | 0x62  | Internal 8MHz RC, CKDIV8 enabled (1MHz actual) |
| hfuse | 0x99  | JTAG enabled, SPIEN enabled |
| efuse | 0xff  | BOD disabled |

### Target Settings

| Fuse  | Value | Description |
|---|---|---|
| lfuse | 0xf7  | External full-swing crystal, no CKDIV8 |
| hfuse | 0xd9  | JTAG disabled, SPIEN enabled |
| efuse | 0xff  | BOD disabled (unchanged) |

## Low Fuse (lfuse) Bit-by-Bit

Current: 0x62 = 0b01100010
Target:  0xf7 = 0b11110111

| Bit | Name | Current | Target | Notes |
|---|---|---|---|---|
| 7 | CKDIV8  | 0 (on)  | 1 (off)| Divide clock by 8. Off = full speed |
| 6 | CKOUT | 1 (off) | 1 (off)| Clock output on PB1. Unchanged |
| 5 | SUT1 | 1 | 1 | Startup time select bit 1 |
| 4 | SUT0 | 0 | 0 | Startup time select bit 0 |
| 3 | CKSEL3  | 0 | 1 | Clock source select |
| 2 | CKSEL2  | 0 | 1 | Clock source select |
| 1 | CKSEL1  | 1 | 1 | Clock source select |
| 0 | CKSEL0  | 0 | 1 | Clock source select |

**CKSEL[3:0] change: 0010 → 0111**
- 0010 = Internal 8MHz RC oscillator (factory default)
- 0111 = Full-swing crystal oscillator, 8-16+ MHz

**Why full-swing crystal?** More reliable oscillation startup, recommended for noisy environments or when driving other clock inputs.

## High Fuse (hfuse) Bit-by-Bit

Current: 0x99 = 0b10011001
Target:  0xd9 = 0b11011001

| Bit | Name | Current | Target | Notes |
|---|---|---|---|---|
| 7 | OCDEN | 1 (off) | 1 (off)| On-chip debug. Unchanged |
| 6 | JTAGEN  | 0 (on)  | 1 (off)| JTAG interface. **Disable to free PC2-PC5** |
| 5 | SPIEN | 0 (on)  | 0 (on) | SPI programming. Must stay enabled! |
| 4 | WDTON | 1 (off) | 1 (off)| Watchdog always on. Unchanged |
| 3 | EESAVE  | 1 (off) | 1 (off)| Preserve EEPROM on erase. Unchanged |
| 2 | BOOTSZ1 | 0 | 0 | Boot size select |
| 1 | BOOTSZ0 | 0 | 0 | Boot size select |
| 0 | BOOTRST | 1 (off) | 1 (off)| Boot reset vector. Unchanged |

**Only change: JTAGEN 0 → 1 (disable JTAG)**

Why disable JTAG? Frees up pins PC2 (TCK), PC3 (TMS), PC4 (TDO), PC5 (TDI) for GPIO use.

## Extended Fuse (efuse)

Current: 0xff = 0b11111111
Target:  0xff = 0b11111111

No changes. BOD (Brown-Out Detection) remains disabled.

## Programming Log

| Date | Action | Command | Result |
|---|---|---|---|
| 2024-12-31 | Initial connection test | `avrdude -c usbasp -p m1284p -B 125kHz` | Success |
| 2024-12-31 | Read fuses | `avrdude -c usbasp -p m1284p -B 125kHz -U lfuse:r:-:h -U hfuse:r:-:h -U efuse:r:-:h` | 0x62, 0x99, 0xff |
| 2024-12-31 | Write fuses | `avrdude -c usbasp -p m1284p -B 125kHz -U lfuse:w:0xf7:m -U hfuse:w:0xd9:m -U efuse:w:0xff:m` | Success, verified |
| 2024-12-31 | Flash LED blink | `avrdude -c usbasp -p m1284p -B 5 -U flash:w:spitfire.hex:i` | 200 bytes, LED blinking at 1 Hz |
| 2025-01-02 | Flash UART test | `avrdude -c usbasp -p m1284p -B 5 -U flash:w:spitfire.hex:i` | 890 bytes, serial output confirmed |
| 2025-01-02 | Crystal test | 18.432 MHz with 15pF caps | Working (22pF failed on breadboard) |

## Serial Debugging Setup

**macOS Sequoia FTDI Driver Issue**: Apple's built-in FTDI DEXT (`com.apple.DriverKit-AppleUSBFTDI.dext`) causes terminal hangs when accessing FTDI serial ports via standard tools (picocom, screen, cat).

**Workaround**: Use "Serial 2" app from Decisive Tactics, which includes its own FTDI driver.
- App Store: Search "Serial 2" by Decisive Tactics
- Works with Sparkfun FTDI Basic Breakout
- Baud rate: 115200, 8N1

**Hardware connection:**
- FTDI RXI → AVR TXD0 (PD1, pin 15)
- FTDI TXO → AVR RXD0 (PD0, pin 14)
- FTDI GND → AVR GND

## Dual Joystick Port Wiring

Two DA-15 ports (Port A and Port B) with interleaved pin assignments.
Even-numbered AVR pins → Port A, Odd-numbered pins → Port B.

See `docs/joystick-detection.md` for automatic type detection algorithm.
See `docs/voltmace-pinouts.md` for complete DA-15 to AVR mapping.

### Analog Inputs (Port A - all 8 channels)

| Function | Port A | Port B | ADC | DA-15 Pin |
|---|---|---|-----|---|
| X axis | PA0 (pin 40) | PA1 (pin 39) | ADC0/1 | 15 |
| Y axis | PA2 (pin 38) | PA3 (pin 37) | ADC2/3 | 7 |
| X_RIGHT | PA4 (pin 36) | PA5 (pin 35) | ADC4/5 | 12 |
| Y_RIGHT | PA6 (pin 34) | PA7 (pin 33) | ADC6/7 | 4 |

Note: PA6/PA7 are Y_RIGHT for Delta 3B Twin, or ROW0 for Delta 14B (mutually exclusive).

### Keypad Matrix (Delta 14B)

**Columns (active-low strobe, high-Z idle):**
| Column | Port A | Port B | DA-15 Pin |
|---|---|---|---|
| COL0 | PB0 (pin 1) | PB1 (pin 2) | 5 |
| COL1 | PB2 (pin 3) | PB3 (pin 4) | 3 |
| COL2 | PC0 (pin 22) | PC1 (pin 23) | 2 |

**Rows (active-low with internal pull-ups):**
| Row | Port A | Port B | DA-15 Pin |
|-----|---|---|---|
| ROW0 | PA6 (pin 34) | PA7 (pin 33) | 4 |
| ROW1 | PC2 (pin 24) | PC3 (pin 25) | 6 |
| ROW2 | PC4 (pin 26) | PC5 (pin 27) | 10 |
| ROW3 | PC6 (pin 28) | PC7 (pin 29) | 13 |

**Button numbering:** switch = row * 3 + column (0-11)

### Other Pins

- **LED:** PD7 (pin 21) - Active-low activity indicator
- **UART:** PD0 (RX), PD1 (TX) - Serial debug at 115200 baud
- **SPI:** PB4 (SS), PB5 (MOSI), PB6 (MISO), PB7 (SCK) - Reserved for BBC Micro
- **VREF:** AVCC (pin 30) ← DA-15 pins 11/14
- **AGND:** GND ← DA-15 pin 8

## Commands Reference

```bash
# Test connection
avrdude -c usbasp -p m1284p -B 125kHz

# Read fuses
avrdude -c usbasp -p m1284p -B 125kHz -U lfuse:r:-:h -U hfuse:r:-:h -U efuse:r:-:h

# Write fuses (CAREFUL!)
avrdude -c usbasp -p m1284p -B 125kHz \
    -U lfuse:w:0xf7:m \
    -U hfuse:w:0xd9:m \
    -U efuse:w:0xff:m

# Flash firmware
avrdude -c usbasp -p m1284p -B 5 -U flash:w:spitfire.hex:i
```

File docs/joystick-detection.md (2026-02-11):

# Joystick Type Detection

SPItFIRE supports automatic detection of connected joystick types using a fully passive algorithm that requires no button presses from the user.

## Supported Joystick Types

| Type | Analog Axes | Buttons | Notes |
|---|---|---|---|
| Delta 14B | 2 (X, Y) | 12 (3x4 keypad) | Full keypad matrix |
| Delta 3B Single | 2 (X, Y) | 3 | Single joystick with fire buttons |
| Delta 3B Twin | 4 (X, Y, X_RIGHT, Y_RIGHT) | 6 | Two joysticks per connector |

## Detection Algorithm

The algorithm exploits the fact that each joystick type repurposes certain DA-15 pins differently.

### Detection Flow

```
         pin 5 pulled LOW?
                |
        +-------+-------+
        |               |
       YES              NO
        |               |
   3B Twin         PA4 ≈ PA0?
   (AGND_RIGHT     (pins 12 & 15 tied?)
    grounded)           |
               +-------+-------+
               |               |
              YES              NO
               |               |
          3B Single      PA0 mid-range?
          (X on both     (valid pot reading?)
           pins)              |
                      +-------+-------+
                      |               |
                     YES              NO
                      |               |
                  Delta 14B      No Joystick
                  (pin 12        (all floating)
                   floating)
```

### Step 1: Check for Delta 3B Twin

**Pin 5 (DA-15) behavior:**
- Delta 14B: COL0 strobe output (floating when not driven)
- Delta 3B Single: Unconnected (floating)
- Delta 3B Twin: AGND_RIGHT (tied to ground)

**Detection:** Configure PB0 (Port A) or PB1 (Port B) as input with internal pull-up. If the pin reads LOW, the joystick is a **Delta 3B Twin**.

### Step 2: Compare Analog Readings (PA0 vs PA4)

**Pin 12 and Pin 15 (DA-15) behavior:**
- Delta 3B Single: Both pins tied together to the X pot wiper
- Delta 14B: Pin 15 is X pot, Pin 12 is unconnected

**Detection:**
- Read ADC channel for PA0 (X axis, pin 15)
- Read ADC channel for PA4 (X_RIGHT, pin 12)
- If values match within threshold (~50 counts) AND PA0 is mid-range → **Delta 3B Single**
- If PA4 is railed (0 or 1023) while PA0 is mid-range → **Delta 14B**

### Step 3: Check for No Joystick

If PA0 is also railed (stuck at 0 or 1023), no valid potentiometer is connected → **No Joystick**.

## Thresholds

| Parameter | Value | Description |
|---|---|---|
| ANALOG_MATCH_THRESHOLD | 50 | Max difference for "equal" analog values |
| ANALOG_LOW_RAIL | 50 | Values below this are considered "railed low" |
| ANALOG_HIGH_RAIL | 973 | Values above this are considered "railed high" |

## Timing

| Operation | Duration |
|---|---|
| Pin 5 check | ~20 µs |
| ADC read (PA0) | ~25 µs |
| ADC read (PA4) | ~25 µs |
| **Total** | **~75 µs** |

Detection is fast enough to run periodically (once per second) for hot-plug support without disrupting normal operation.

## Limitations

1. **PA6/PA7 dual use**: These pins are Y_RIGHT analog for Delta 3B Twin, but ROW0 digital for Delta 14B. The firmware must reconfigure these pins based on detected type.

2. **Mid-range assumption**: Detection assumes the joystick pot is not at an extreme position during detection. If the pot is exactly at 0 or 1023, detection may incorrectly report "No Joystick".

3. **Electrical noise**: In noisy environments, the analog threshold may need adjustment.

## Pin Reference

### DA-15 Pin Usage by Joystick Type

| DA-15 Pin | Delta 14B | Delta 3B Single | Delta 3B Twin |
|---|---|---|---|
| 2 | COL2 | - | - |
| 3 | COL1 | COL1 | ROW3_RIGHT |
| 4 | ROW0 | Y (tied to pin 7) | Y_RIGHT |
| 5 | COL0 | - | AGND_RIGHT |
| 6 | ROW1 | - | ROW3_LEFT |
| 7 | Y | Y | Y_LEFT |
| 8 | AGND | AGND | AGND_LEFT |
| 10 | ROW2 | ROW3 | COL1_RIGHT |
| 12 | - | X (tied to pin 15) | X_RIGHT |
| 13 | ROW3 | ROW4 | COL1_LEFT |
| 14 | VREF | VREF | VREF_LEFT |
| 15 | X | X | X_LEFT |

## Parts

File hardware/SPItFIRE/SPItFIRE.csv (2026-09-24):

Reference | Qty | Value | Footprint
C1,C4,C5,C7,C8,C9,C10 | 7 | 100nF | Capacitor_SMD:C_0603_1608Metric_Pad1.08x0.95mm_HandSolder
C2,C6 | 2 | pF | Capacitor_SMD:C_0201_0603Metric_Pad0.64x0.40mm_HandSolder
C3 | 1 | 10uF | LED_SMD:LED_0603_1608Metric_Pad1.05x0.95mm_HandSolder
D1 | 1 | 1N4148W | Diode_SMD:D_SOD-123
D2 | 1 | LED | LED_SMD:LED_0603_1608Metric_Pad1.05x0.95mm_HandSolder
J1 | 1 | Compact Host | SPItFIRE:DE9_Female_Horizontal_P2.74x2.84mm_EdgePinOffset10.40mm_Housed_MountingHolesOffset12.5mm
J2 | 1 | User Port Host | Connector_IDC:IDC-Header_2x10_P2.54mm_Latch_Horizontal
J3 | 1 | User Port Passthrough | Connector_IDC:IDC-Header_2x10_P2.54mm_Vertical
J4 | 1 | SD Card Adapter | Connector_PinSocket_2.54mm:PinSocket_1x08_P2.54mm_Vertical
J5 | 1 | DeadOnRTC | Connector_PinSocket_2.54mm:PinSocket_1x07_P2.54mm_Vertical
J6 | 1 | SPI_4 | Connector_PinSocket_2.54mm:PinSocket_1x06_P2.54mm_Vertical
J7 | 1 | SPI_5 | Connector_PinSocket_2.54mm:PinSocket_1x06_P2.54mm_Vertical
J8 | 1 | SPI_6 | Connector_PinSocket_2.54mm:PinSocket_1x06_P2.54mm_Vertical
J9 | 1 | SPI_7 | Connector_PinSocket_2.54mm:PinSocket_1x06_P2.54mm_Vertical
J10 | 1 | ISP | Connector_IDC:IDC-Header_2x03_P2.54mm_Vertical
J11 | 1 | Joystick A | SPItFIRE:DA15_Female_Horizontal_P2.74x2.84mm_EdgePinOffset10.40mm_Housed_MountingHolesOffset16.66mm
J12 | 1 | Joystick B | SPItFIRE:DA15_Female_Horizontal_P2.74x2.84mm_EdgePinOffset10.40mm_Housed_MountingHolesOffset16.66mm
J13 | 1 | Peripheral DE-9 | SPItFIRE:DE9_Male_Horizontal_P2.74x2.84mm_EdgePinOffset10.40mm_Housed_MountingHolesOffset12.5mm_1
J14 | 1 | Peripheral User Port | Connector_IDC:IDC-Header_2x10_P2.54mm_Latch_Horizontal
L1 | 1 | 10uH | Inductor_SMD:L_0805_2012Metric_Pad1.05x1.20mm_HandSolder
R1 | 1 | 10K | Capacitor_SMD:C_0603_1608Metric_Pad1.08x0.95mm_HandSolder
R2 | 1 | 560R | Capacitor_SMD:C_0603_1608Metric_Pad1.08x0.95mm_HandSolder
R3,R4,R5,R6 | 4 | 1K | Capacitor_SMD:C_0603_1608Metric_Pad1.08x0.95mm_HandSolder
RV102 | 1 | 10K
U1 | 1 | 74HC138 | Package_SO:SOIC-16_3.9x9.9mm_P1.27mm
U2 | 1 | ATmega1284P-A | Package_QFP:TQFP-44_10x10mm_P0.8mm
Y1 | 1 | Crystal | Crystal:Crystal_SMD_5032-4Pin_5.0x3.2mm

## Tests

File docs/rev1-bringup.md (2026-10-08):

# Rev 1 PCB Bring-up Log

Record of bringing up the first assembled Rev 1 SPItFIRE PCB. Connectors
are fitted just-in-time, one subsystem at a time, so that expensive
connectors are not lost to a faulty board.

## Board 1 - 2026-10-03

### Initial power-up via ISP

First connection of the USBasp (5 V jumper fitted, powering the board)
caused the USBasp's red power LED to go out, indicating the 5 V rail was
being pulled down. The board was disconnected immediately; the USBasp and
the host USB port were unharmed.

After reflowing the solder joints on the ATmega1284P (TQFP-44), the fault
cleared. With the USBasp reconnected its power LED stayed lit, and 5.09 V
was measured at all unpopulated connector footprints where expected and
across the 74HC138 supply pins.

### ISP communication and fuses

The factory-fresh AVR was read at a slow ISP clock (`-B 32`, 16 kHz),
since a new part runs from the internal 8 MHz RC oscillator divided by 8.

| | Factory | Written |
|---|---|---|
| Signature | `1E 97 05` (ATmega1284P) | - |
| Low fuse | `0x62` (internal RC, CKDIV8) | `0xF7` (full-swing crystal, no CKDIV8) |
| High fuse | `0x99` (JTAG enabled) | `0xD9` (JTAG disabled, frees PC2-PC5) |
| Extended fuse | `0xFF` (BOD off) | `0xFF` |
| Lock | `0xFF` | unchanged |

Fuses were written at the slow ISP clock, with the low fuse (clock
source) written last.

The 18.432 MHz crystal was verified by reading the signature at a 1.5 MHz
ISP clock. This is only possible with a CPU clock above 6 MHz, so it
proves the crystal oscillator is running (the old 1 MHz internal clock
would fail). Normal programming uses `-B 5` (187.5 kHz).

### Status LED

The status LED on Rev 1 is **active-high** (PD7 -> R2 -> D2 -> GND),
the opposite of the breadboard prototype. Initial firmware left the LED
lit after startup. The firmware was changed to a shared `status_led`
module: three quick flashes on reset, then a once-per-second
double-flash heartbeat driven by a Timer0 compare interrupt at 100 Hz.
The LED was fitted the correct way round.

### Host DE-9 (J1) and power from the Master Compact

J1 fitted. Pinout verified against the PCB netlist and
[spi-interface.md](spi-interface.md); CB1 (pin 5) is tied to SCK (pin 3)
on the PCB, replacing the external wire used on the prototype.

Powered from the Master Compact through a 0.5 m DE-9 to DE-9 cable, the
board's 5 V rail measured **4.85 V**. This is within the ATmega1284P
specification for 18.432 MHz (4.5-5.5 V for 0-20 MHz).

Brown-out detection is currently disabled. Enabling 4.3 V BOD (extended
fuse `0xFC`) is worth considering, so that the AVR resets cleanly if the
supply sags below the 4.5 V needed at this clock speed.

#### USBasp caveats when the Compact powers the board

- J1 pin 7 connects the Compact's +5 V directly to the board's 5 V rail.
  **Remove the USBasp's 5 V jumper** (or unplug the USBasp) whenever the
  Compact is connected, otherwise two supplies drive the same rail.
- An **unpowered** USBasp attached to the ISP header holds the AVR in
  reset: RESET, SCK and MOSI are pulled low through the input protection
  diodes of its unpowered ATmega8, and the heartbeat stops. A powered
  USBasp (jumper removed) can stay attached; its pins idle in a
  high-impedance state between programming sessions.

### 74HC138 decoder

SPIWALK (about 2.1 s per address) was run from the Compact and checked
with a logic probe:

- A0-A2 (pins 1-3) count correctly.
- Y0-Y7 each go low in turn, synchronised with the address shown on the
  BBC display.
- Each Y output reaches its connector, J4-J9 inclusive.
- Y1 feeds the AVR's SS pin.

### SPI data path

AVR running the `spitest` firmware (reply = received byte XOR &55):

| Test | Result |
|---|---|
| SPITEST (bit-bang) | No bad transfers |
| SPITTEST (turbo, VIA shift register via CB1) | No bad transfers |

Both were run past &0100 good transfers, covering every byte value on
MOSI and MISO.

### Throughput

| Mode | Prototype (breadboard) | Rev 1 |
|---|---|---|
| Bit-bang (SPIPERF) | 4,124 bytes/s | 4,147 bytes/s |
| Turbo (SPITPERF) | 7,371 bytes/s | 7,388 bytes/s |

Throughput is set by the 6502 transfer loops rather than the board, so
matching figures are expected. The longer cable and the PCB layout
introduced no errors.

### Peripheral DE-9 (J13) - mirrored footprint

J13 fitted (male DE-9). Measuring the connector directly (looking into
the pins, wide row uppermost, pin 1 top-left) gave **pin 7 = 0 V and
pin 8 = 4.8 V**: power and ground are swapped.

Cause: the custom male footprint
`DE9_Male_..._MountingHolesOffset12.5mm_1.kicad_mod` has pad coordinates
identical to the custom female footprint used for J1. Male and female
footprints must be mirror images (compare KiCad's stock `DSUB-9_Pins`,
pins running +x, with `DSUB-9_Socket`, pins running -x). The female
footprint is correct (J1 works with the Compact via a straight cable);
the male footprint was not mirrored when it was created.

Effect on Rev 1 (physical J13 pin -> signal): 1=PD4, 2=PD3, 3=PD2,
4=PD1, 5=PD0, 6=PD6, 7=GND, 8=+5V, 9=PD5.

**On a Rev 1 board with J13 fitted on the component side, do not plug a
mouse directly into J13** - Compact, Amiga and Atari mice take +5 V on
pin 7 and would be reverse-powered. Software remapping cannot correct the
swapped supply pins.

Two workarounds restore the designed pinout, so the mouse firmware and
[peripheral-pinouts.md](peripheral-pinouts.md) apply unchanged:

1. **Fit J13 on the reverse (solder) side of the board** (adopted on
   board 1). Mounting the right-angle connector on the opposite side
   mirrors it relative to the footprint, cancelling the footprint's
   mirroring. The connector still faces out of the same board edge, but
   upside down. Verified on board 1: pin 7 = 4.8 V, pin 8 = 0 V, and
   serial transmit and receive work through PD0/PD1 on pins 1/2.
2. A mirroring adapter (female on the board side, male on the
   peripheral side) wired 1-5, 2-4, 3-3, 4-2, 5-1, 6-9, 7-8, 8-7, 9-6.
   Used initially; replaced by option 1 as the chained breakouts were
   fragile.

The custom female DA-15 footprint used for J11/J12 was checked against
KiCad's stock `DSUB-15_Socket` and has the correct handedness.

### Serial (USART0) via the Peripheral DE-9

With the designed pinout restored (first via the mirroring adapter, then
with J13 re-mounted on the reverse side), a USB-TTL serial adapter was connected
to the designed Peripheral DE-9 pins: pin 1 (PD0, AVR RX, TQFP pin 9) to
the adapter's TXD, pin 2 (PD1, AVR TX, TQFP pin 10) to its RXD, and
pin 8 to GND. Continuity was checked end to end from the AVR pins.

Running the joystick firmware (`spitfire` target) at 115200 8N1:

- Transmit: periodic status lines received cleanly at the 100 ms
  reporting interval. 18.432 MHz gives an exact divisor (UBRR = 9,
  0% baud error).
- Receive: sending `3` set Port A to Delta 14B and the firmware
  confirmed `Port A: Delta 14B`; sending `0` restored `No Joystick`.

With J11 not yet fitted, Port A's ADC inputs float (readings around
700/690 of 1023), as expected.

Lesson from this step: DE-9 breakout boards may label their screw
terminals for one of their two connectors only. Check continuity to the
AVR pins themselves rather than trusting connector numbering when
several breakouts and adapters are chained.

### Joystick A (J11) - Delta 3B Twin

J11 fitted (female DA-15). Before soldering, the custom DA-15 footprint
was checked against KiCad's stock `DSUB-15_Socket` and the proven J1
female DE-9 footprint: same pin direction, row placement and second-row
offset. With the board powered, J11 pins 11 and 14 (VREF, from AVCC via
L1) read 4.85 V.

Delta 3B Twin connected, Port A set to 3B Twin over serial (`1`):

| | Left handset | Right handset |
|---|---|---|
| X at rest | 564 | 536 |
| Y at rest | 506 | 534 |
| X range | 0-1023 | 2-1023 |
| Y range | 0-1023 | 2-1023 |
| Fire button | Reported as `L` only | Reported as `R` only |

Rest readings were stable to within about 2 counts. Moving either
handset through its full range changed the other handset's readings by
at most 1 count, so there is no crosstalk between the four ADC
channels, and each handset and fire button maps to the correct side.

### Joystick A (J11) - Delta 3B Single

Delta 3B Single connected, Port A set to 3B Single over serial (`2`).
At rest X=495, Y=583, stable to 1 count. X and Y each covered the full
0-1023 range. The three physical buttons registered as two separate
left-fire (`L`) presses and one right-fire (`R`) press, matching the
handset's wiring (two buttons on PB0, one on PB1). The axes stayed
within 1 count while buttons were pressed.

The 3B Single drives both pot pairs so it can act as either player's
handset. With Port A switched to 3B Twin mode (`1`) to report all four
channels, the second pair (ADC4/ADC6, J11 pins 12 and 4) covered
0-1023 and tracked the primary pair (ADC0/ADC2) exactly: correlation
+1.000 on both axes, mean difference under 1 count, same direction, no
X/Y swap. Each wiper is evidently connected to both channels in
parallel.

### Joystick A (J11) - Delta 14B

Delta 14B connected, Port A set to 14B over serial (`3`). At rest
X=509, Y=502, keypad `FFF` (no buttons). X and Y each covered 0-1023.

Pressing the keypad from bottom-left to top-right, row by row, produced
buttons 0-11 in order, each as a single cleared bit (`FFE`, `FFD`,
`FFB` ... `7FF`), with no ghosting or multiple keys reported. The two
extra physical buttons, wired in parallel with button 10, both reported
as button 10 (`BFF`). The axes stayed within 1-3 counts while keys were
pressed, so keypad scanning does not disturb the ADC.

With the 3B Twin, 3B Single and 14B results, every Port A signal on J11
is verified: ADC0/2/4/6, both fire inputs and the full 3x4 keypad matrix.

### Joystick B (J12) - Delta 3B Twin, with Port A as a crosstalk reference

J12 fitted; pins 11 and 14 read 4.85 V. A second Delta 3B Twin was
connected to J12 while the first remained on J11, and both ports were
set to 3B Twin over serial (`1`, `5`). The Port A handsets were left
untouched while Port B was exercised.

| | Left X | Left Y | Right X | Right Y |
|---|---|---|---|---|
| Port B range | 0-1023 | 0-1023 | 0-1023 | 0-1023 |

- Each Port B handset moved only its own channels; three left-fire
  and three right-fire presses registered on Port B only.
- Port A's left handset held a constant reading (zero spread) while the
  Port B left handset swept its full range. It later stepped once,
  permanently, by about 20 counts at the moment the Port B right handset
  was picked up, which is consistent with a physical nudge (Delta
  handsets stay where they are left), not electrical crosstalk.
- Port A's right handset stayed within 1 count throughout.

### Joystick B (J12) - Delta 14B

Delta 14B connected to J12 (Port B set to 14B, `7`), with the 3B Twin
left on J11 as a reference. At rest X=488, Y=499, keypad `FFF`. X and Y
each covered 0-1023. Buttons 0-11 were reported in order, one bit each,
with no ghosting, and the two extra buttons reported as button 10. The
axes stayed within 2 counts while keys were pressed. The untouched
Port A channels varied by at most 1 count and reported no fire events.

With the 3B Twin and 14B results, every Port B signal on J12 is
verified: ADC1/3/5/7, both fire inputs and the full 3x4 keypad matrix.

### Mouse on the Peripheral DE-9 (J13) - Golden Image GI-6000

Firmware: `spimouse` (quadrature decoding on Port D via the PCINT3
pin-change interrupt). Test program: SPIMOUSE on the Master Compact.

The Golden Image GI-6000 is an optical mouse (it needs its own printed
pad) with a switch selecting Amiga or Atari wiring, so one mouse tests
both pinouts. It was plugged directly into the re-mounted J13.

| Mouse switch | SPIMOUSE mode | Result |
|---|---|---|
| Amiga | `2` (Amiga) | Both axes and all three buttons working |
| Atari | `3` (Atari) | Both axes and left/right buttons working |

No middle button in Atari mode is expected: the Atari pinout leaves
pin 5 unconnected and the firmware's Atari button table has no middle
button, matching standard two-button Atari mice.

### Peripheral User Port (J14) - AMX-compatible mice

J14 (20-way header) was checked against the adapter wiring in
[peripheral-pinouts.md](peripheral-pinouts.md) before fitting: every
signal pin matches, pins 1 and 3 are +5V and the odd pins 5-19 are GND.
Its pad numbering matches KiCad's stock 2x10 IDC header (not mirrored).
J13 and J14 share Port D, so only one peripheral connector is used at a
time.

An AMX mouse in SPIMOUSE mode `1` (AMX/Compact) gave both axes working,
confirming the AMX quadrature path (PD4/PD0/PD6/PD3). Buttons:

| | Left (pin 16, PD5) | Right (pin 20, PD1) |
|---|---|---|
| AMX mouse | Working | Not working |
| Second AMX-compatible mouse | Not working | Working |

Each J14 button path works with at least one mouse; a fault on J14
would break the same button on both. The failures are therefore in the
(old) mice, not the board.

### RTC header (J5) - SparkFun DeadOn DS3234

J5's pin order (GND, VCC, SQW, CLK, MISO, MOSI, SS) matches the DeadOn
breakout header; SQW is not connected. The RTC is selected by `~SS_3`,
decoder output Y3 (`DEV_RTC = %00001100`). No backup battery fitted.

**SPI mode.** The DS3234 picks its clock polarity from the state of SCLK
when CS falls. The 6522 shift register samples MISO on the rising edge
of CB1 (as MMFS assumes; MMFS idles the clock high). With SCLK low at CS,
the DS3234 would change DOUT on rising edges, racing the VIA's sample.
SCK is therefore idled **high** before the RTC is selected, giving
CPOL=1/CPHA=1: DOUT changes on falling edges and both ends sample on
rising edges. (The AVR is SPI mode 0 and is unaffected: it is only
selected with SCK idling low.)

New BBC test program SPIRTC (`beeb/spitest/src/spirtc.asm`):

| Test | Result |
|---|---|
| Write `55 AA 00 FF 01 80 5A A5` to SRAM, burst read back | Identical (`OK`) |
| Control register (0Eh) | `1C`, the power-on default |
| Status register (0Fh) | `C8` (OSF, BB32kHz, EN32kHz), the power-on default with no battery |
| Time/date burst read (00h-06h) | Counting from 00:00:00 01/01/2000, seconds advancing once per second |
| Temperature (11h-12h) | 23.50 C |

Register values matching their power-on defaults exactly confirm bit
alignment in both directions.

A second program, SPISETTIME (`beeb/spitest/src/spisettime.asm`), prompts
for the date and time, computes the day of the week (Sakamoto's method,
checked against Python's calendar for every date 2000-2099), waits for a
key press so the clock starts on an exact second, burst-writes registers
00h-06h and clears OSF. After setting, SPIRTC showed the new time
ticking and the status register no longer flagged OSF, confirming writes
to the time and status registers.

With a CR1225 backup cell fitted, the board was powered off for five
minutes and powered on again: the RTC had kept time throughout and OSF
remained clear.

### SD card header (J4) - Adafruit MicroSD breakout+

J4's pin order (5V, 3V, GND, CLK, DO, DI, CS, CD) matches the Adafruit
breakout; 3V and CD are not connected. The breakout regulates its own
3.3 V and level-shifts CLK/DI/CS with a 74HC4050; DO reaches MISO at
3.3 V, above the 6522's 2.0 V input threshold. The card is selected by
`~SS_2`, decoder output Y2 (`DEV_SD = %00001000`).

New BBC test program SPISD (`beeb/spitest/src/spisd.asm`), SPI mode 3
(SCK idling high, as MMFS). Because an SD card keeps driving DO for a
few clocks after CS goes high, every deselect is followed by one byte of
clocks with no device selected, so the card cannot contend with other
devices on the shared MISO line.

All steps passed with a card inserted: 80 power-up clocks, CMD0
(R1=01), CMD8 (SD v2, R7 echo correct), ACMD41 until ready (R1=00),
CMD58 (OCR read), CMD10 (CID read, with sensible manufacturer, product
name, serial number and date) and CMD17 (sector 0 read, with a valid
55 AA signature and partition entry).

Card used: a SanDisk 16 GB microSDHC. CID as reported by SPISD:

| Field | Value |
|---|---|
| Manufacturer ID | `03` (SanDisk) |
| OEM ID | `SD` |
| Product name | `SC16G` |
| Revision | 8.0 |
| Serial number | `AC9304AB` |
| Manufacture date | 2018/04 |

### Expansion SPI headers (J6-J9) - continuity checked

Four 6-pin headers for future SPI add-ons, one per spare decoder output,
all with the same project-specific pinout:

| Pin | 1 | 2 | 3 | 4 | 5 | 6 |
|---|---|---|---|---|---|---|
| Signal | SCK | +5V | MISO | GND | MOSI | `~SS_n` |

| Header | Chip select | Decoder output | Device constant |
|---|---|---|---|
| J6 | `~SS_4` | Y4 | `%00010000` |
| J7 | `~SS_5` | Y5 | `%00010100` |
| J8 | `~SS_6` | Y6 | `%00011000` |
| J9 | `~SS_7` | Y7 | `%00011100` |

No add-ons exist yet. Each chip select was checked for continuity from
the 74HC138 and power was confirmed at each header. SCK, MISO and MOSI
are the shared nets already proven end to end by the AVR, RTC and SD
card, and SPIWALK showed Y4-Y7 switching correctly. Considered low risk.

### Host User Port (J2) and User Port Passthrough (J3) - not yet tested

J2 is the alternative host connection for a BBC Micro or Master with a
20-way User Port (instead of J1 for the Master Compact). J3 passes the
User Port through to further devices that do not use the SPItFIRE's pin
allocations; it is only useful when the host is connected via J2.

No machine with a working 20-way User Port was available, so neither
was tested. Netlist check: J2 pins 2/4/6/8/10/12/14 (CB1, CB2, PB0-PB4)
carry SCK, MISO, MOSI, SCK, A0, A1, A2, the same nets proven end to end
through J1; pins 16/18/20 (PB5-PB7) go only to J3. The untested parts are
therefore the connectors themselves and the PB5-PB7 passthrough tracks.
Considered low risk.

### Bus idle levels - no pull resistors on the shared SPI nets

The netlist has no pull resistors on MISO, MOSI, SCK or the decoder
inputs A0-A2 (the only resistors are R3-R6, the 1k series resistors to
the AVR). Two consequences:

**MISO floats when no device drives it.** With no device selected, or
with the selected device absent (e.g. no DeadOn on J5), the VIA's CB2
input reads whatever the floating line settles at, so software cannot
reliably tell that nothing answered. A pull-up makes an absent device
read `&FF` on every SPI device. Proposed: 10k to +5V. When the AVR
drives low through its 1k series resistor (R5) the line sits at about
0.45 V, still a good low; the SD breakout's 3.3 V DO is fed only about
0.1 mA when tri-stated. Rev 1 bodge, no soldering: a 10k resistor
across **pins 2 (+5V) and 3 (MISO)** of a spare expansion header
(J6-J8). Not pins 3-4: pin 4 is GND, and that would pull MISO down.

The SPItFIRE ROM does not rely on the pull-up: it validates what the
DS3234 returns before claiming a clock call (see
[rom-design.md](rom-design.md)), so Rev 1 boards without the bodge
still fall back to ANFS or the MOS when the RTC is absent.

**The decoder selects whatever A0-A2 float to** whenever the VIA is not
driving PB2-PB4: at power-up and reset (port B is all inputs), before
any SPItFIRE software has set the port up, and when the cable is
plugged into a running machine.

Measured on the Compact with SPItFIRE attached (the 74HC138 inputs draw
at most about 1 uA, so the board does not load these lines), probing
A0/A1/A2 at J3 pins 10/12/14 against GND on the facing pins 9/11/13:

| Condition | A0-A2 | Selected |
|---|---|---|
| `?&FE62=&1F` then `?&FE60=0` / `?&FE60=&1C` | 0 V / 4.9 V | (pin mapping check) |
| `?&FE62=0` (port B inputs, as after reset) | 4.95 V | Y7 (J9 pin 6 low, all other chip selects high) |
| Same, with 10k from each line to GND in turn | 3.5 V | |
| After Ctrl-BREAK, and after power-on | 4.95 V | Y7 |
| After `*TIME` (the SPItFIRE ROM sets the port up) | 0 V | Y0 |

So the Compact pulls PB2-PB4 up, with about 4.1k each
(10k x (4.95 - 3.5) / 3.5), as expected on a joystick port whose
switches pull lines to ground; and nothing at boot touches port B with
ANFS and the SPItFIRE ROM loaded (MMFS was not loaded for these
measurements). With the port released, the decoder selects **Y7**.

Pull-downs to keep Y0 as "no device" are impractical: to pull a line
below the 74HC138's input-low threshold (about 1.35 V) against 4.1k they
would need to be about 1.5k or less, and the VIA's NMOS port B outputs
cannot then drive a good high (about 3 mA into the pull-down).

**Decision for Rev 2: Y7 is "no device".** The Compact's pull-ups make
all-ones the resting state, so every unconfigured moment selects
nothing without extra parts. Leave Y7 unconnected (as Y0 is on Rev 1)
and move the spare expansion header that was on Y7 (J9) to Y0.
Optionally add weak on-board pull-ups (47k-100k) on A0-A2, which only
matter when the board is powered without the Compact (e.g. from the
USBasp); not 10k, which with the Compact's 4.1k would make the VIA sink
about 1.7 mA per line when driving low, at its 1.6 mA rating.

Software change, which also works on Rev 1 as long as J9 stays empty:
"no device" is now `%00011100` (Y7) instead of `%00000000` (Y0), in the
test programs (`DEV_NONE`/deselect), the ROM (`spi_init`,
`spi_deselect`), and the MMFS driver (`nosel`). Done; on Rev 1 this
gives six usable chip selects (Y1-Y6), on Rev 2 seven (Y0-Y6).

On Rev 1, keep J9 empty: it is selected whenever port B is released.

SCK and MOSI need no resistors: devices ignore them while deselected.

### Rev 2 errata

| # | Issue | Fix |
|---|---|---|
| 1 | J13 male DE-9 footprint mirrored (pins 1-5, 2-4, 6-9, 7-8 swapped) | Negate pad X coordinates in the custom male DE-9 footprint so it mirrors the female footprint |
| 2 | MISO floats when no device drives it, so an absent device reads noise | 10k pull-up from MISO to +5V (Rev 1 bodge: 10k across pins 2-3 of J6, J7 or J8) |
| 3 | When the VIA is not driving A0-A2, the Compact's own ~4.1k pull-ups make the decoder select Y7, which goes to expansion header J9 | Make Y7 "no device": leave Y7 unconnected and move J9 to Y0; optional 47k-100k pull-ups on A0-A2; software "no device" code becomes `%00011100` (see "Bus idle levels") |

### Status

| Subsystem | Status |
|---|---|
| Power (from Compact) | Working, 4.85 V |
| ISP programming, fuses, crystal | Working |
| Status LED | Working (active-high) |
| 74HC138 decoder, J4-J9 chip selects | Working |
| SPI, bit-bang and turbo | Working, no errors |
| Joystick A (J11) | Working: Delta 3B Twin, 3B Single and 14B; all pins verified |
| Joystick B (J12) | Working: Delta 3B Twin and 14B; all pins verified, no crosstalk with Port A |
| Peripheral DE-9 (J13) | Working; fitted on reverse side to correct mirrored footprint (erratum 1) |
| Serial (USART0, 115200 8N1) | Working, transmit and receive |
| Mouse on J13, Amiga and Atari modes | Working (Golden Image GI-6000) |
| Peripheral User Port (J14), AMX mode | Working (button faults traced to the mice) |
| RTC (J5, DS3234 DeadOn) | Working: SRAM, set/read time, status, temperature, battery backup; `*TIME` and `TIME$` through the SPItFIRE ROM |
| SD card (J4, Adafruit microSD) | Working: initialisation, CID and sector reads; MMFS2 with the SPItFIRE device driver |
| Expansion headers (J6-J9) | Continuity and power checked; no add-ons yet |
| Host User Port (J2), passthrough (J3) | Not tested (no 20-way User Port host available); netlist checked |

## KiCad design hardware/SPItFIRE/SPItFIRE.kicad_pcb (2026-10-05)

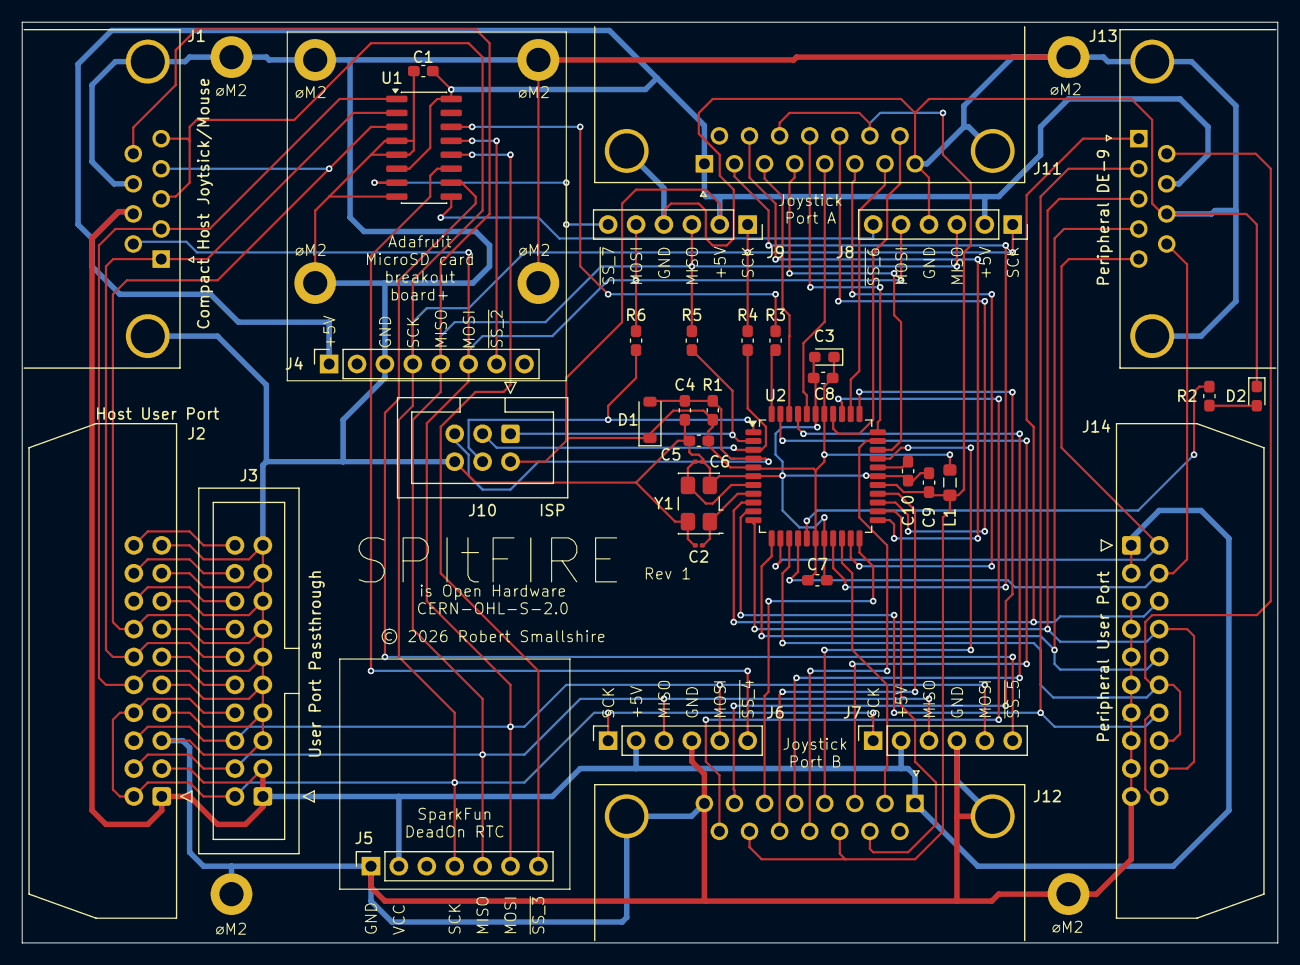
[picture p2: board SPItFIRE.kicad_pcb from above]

Board: 2 copper layers, 114.3 x 83.8 mm, 44 parts (0 on the bottom side), 56 nets.

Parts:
C1, C4, C5, C7, C8, C9, C10: 100nF; C_0603_1608Metric_Pad1.08x0.95mm_HandSolder
C2, C6: C_Small; C_0201_0603Metric
C3: 10uF; LED_0603_1608Metric_Pad1.05x0.95mm_HandSolder
D1: 1N4148W; D_SOD-123
D2: LED; LED_0603_1608Metric_Pad1.05x0.95mm_HandSolder
H301, H302, H303, H304, H305, H306, H307, H308: MountingHole_Pad; MountingHole_2.2mm_M2_DIN965_Pad
J1: Compact Host Joytsick/Mouse; DE9_Female_Horizontal_P2.74x2.84mm_EdgePinOffset10.40mm_Hou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
J2: Host User Port; IDC-Header_2x10_P2.54mm_Latch_Horizontal
J3: User Port Passthrough; IDC-Header_2x10_P2.54mm_Vertical
J4: SD Card Adapter; PinSocket_1x08_P2.54mm_Vertical
J5: DeadOnRTC; PinSocket_1x07_P2.54mm_Vertical
J6: SPI_4; PinSocket_1x06_P2.54mm_Vertical
J7: SPI_5; PinSocket_1x06_P2.54mm_Vertical
J8: SPI_6; PinSocket_1x06_P2.54mm_Vertical
J9: SPI_7; PinSocket_1x06_P2.54mm_Vertical
J10: ISP; IDC-Header_2x03_P2.54mm_Vertical
J11: Joystick A; DA15_Female_Horizontal_P2.74x2.84mm_EdgePinOffset10.40mm_Ho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
J12: Joystick B; DA15_Female_Horizontal_P2.74x2.84mm_EdgePinOffset10.40mm_Ho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
J13: Peripheral DE-9; DE9_Male_Horizontal_P2.74x2.84mm_EdgePinOffset10.40mm_House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
J14: Peripheral User Port; IDC-Header_2x10_P2.54mm_Latch_Horizontal
L1: 10uH; L_0805_2012Metric_Pad1.05x1.20mm_HandSolder
R1: 10K; C_0603_1608Metric_Pad1.08x0.95mm_HandSolder
R2: 560R; C_0603_1608Metric_Pad1.08x0.95mm_HandSolder
R3, R4, R5, R6: 1K; C_0603_1608Metric_Pad1.08x0.95mm_HandSolder
U1: 74HC138; SOIC-16_3.9x9.9mm_P1.27mm
U2: ATmega1284P-A; TQFP-44_10x10mm_P0.8mm
Y1: Crystal; Crystal_SMD_5032-4Pin_5.0x3.2mm

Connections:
+5V: C1.1, C3.1, C5.1, C7.1, C8.1, D1.1 (K), J1.7, J2.1, J2.3, J3.1, J3.3, J4.1, J5.2, J6.2, J7.2, J8.2, J9.2, J10.2, J11.1, J12.1, J13.7, J14.1, J14.3, L1.1, R1.1, U1.6 (E2), U1.16 (VCC), U2.5 (VCC1), U2.17 (VCC2), U2.38 (VCC3)
/main/A0: J1.2, J2.10, J3.10, U1.1 (A0)
/main/A1: J1.1, J2.12, J3.12, U1.2 (A1)
/main/A2: J1.4, J2.14, J3.14, U1.3 (A2)
/main/AVR_MISO: J10.1, R5.2, U2.2 (PB6)
/main/AVR_MOSI: J10.4, R6.2, U2.1 (PB5)
/main/AVR_SCK: J10.3, R4.2, U2.3 (PB7)
/main/~AVR_SS: R3.2, U2.44 (PB4)
AVCC: C9.1, J11.11 (P111), J11.14, J12.11 (P111), J12.14, L1.2, U2.27 (AVCC)
GND: C1.2, C2.2, C3.2, C4.2, C5.2, C6.2, C7.2, C8.2, C9.2, C10.2, D2.1 (K), H301.1 (1_1), H302.1 (1_1), H303.1 (1_1), H304.1 (1_1), H305.1 (1_1), H306.1 (1_1), H307.1 (1_1), H308.1 (1_1), J1.8, J1.SH (PAD), J2.5, J2.7, J2.9, J2.11, J2.13, J2.15, J2.17, J2.19, J3.5, J3.7, J3.9, J3.11, J3.13, J3.15, J3.17, J3.19, J4.3, J5.1, J6.4, J7.4, J8.4, J9.4, J10.6, J11.8, J11.SH (PAD), J12.8, J12.SH (PAD), J13.8, J13.SH (PAD), J14.5, J14.7, J14.9, J14.11, J14.13, J14.15, J14.17, J14.19, U1.4 (~E0), U1.5 (~E1), U1.8 (GND), U2.6 (GND1), U2.18 (GND2), U2.28 (GND4), U2.39 (GND3), Y1.2 (G), Y1.4 (G)
MISO: J1.9, J2.4, J3.4, J4.5, J5.5, J6.3, J7.3, J8.3, J9.3, R5.1
MOSI: J1.6, J2.6, J3.6, J4.6, J5.6, J6.5, J7.5, J8.5, J9.5, R6.1
unnamed: D2.2 (A), R2.2
unnamed: J2.16, J3.16
unnamed: J2.18, J3.18
unnamed: J2.20, J3.20
unnamed: R2.1, U2.16 (PD7)
unnamed: C2.1, U2.8 (XTAL1), Y1.1
unnamed: C6.1, U2.7 (XTAL2), Y1.3
unnamed: C10.1, U2.29 (AREF)
PA0: J11.15, U2.37 (PA0)
PA1: J12.15, U2.36 (PA1)
PA2: J11.7, U2.35 (PA2)
PA3: J12.7, U2.34 (PA3)
PA4: J11.12, U2.33 (PA4)
PA5: J12.12, U2.32 (PA5)
PA6: J11.4, U2.31 (PA6)
PA7: J12.4, U2.30 (PA7)
PB0: J11.5, U2.40 (PB0)
PB1: J12.5, U2.41 (PB1)
PB2: J11.3, U2.42 (PB2)
PB3: J12.3, U2.43 (PB3)
PC0: J11.2, U2.19 (PC0)
PC1: J12.2, U2.20 (PC1)
PC2: J11.6, U2.21 (PC2)
PC3: J12.6, U2.22 (PC3)
PC4: J11.10, U2.23 (PC4)
PC5: J12.10, U2.24 (PC5)
PC6: J11.13, U2.25 (PC6)
PC7: J12.13, U2.26 (PC7)
PD0: J13.1, J14.6, U2.9 (PD0)
PD1: J13.2, J14.14, J14.20, U2.10 (PD1)
PD2: J13.3, J14.8, J14.18, U2.11 (PD2)
PD3: J13.4, J14.10, U2.12 (PD3)
PD4: J13.5, J14.2, U2.13 (PD4)
PD5: J13.6, J14.12, J14.16, U2.14 (PD5)
PD6: J13.9, J14.4, U2.15 (PD6)
SCK: J1.3, J1.5, J2.2, J2.8, J3.2, J3.8, J4.4, J5.4, J6.1, J7.1, J8.1, J9.1, R4.1
~AVR_RESET: C4.1, D1.2 (A), J10.5, R1.2, U2.4 (~RESET)
~SS_1: R3.1, U1.14 (~Y1)
~SS_2: J4.7, U1.13 (~Y2)
~SS_3: J5.7, U1.12 (~Y3)
~SS_4: J6.6, U1.11 (~Y4)
~SS_5: J7.6, U1.10 (~Y5)
~SS_6: J8.6, U1.9 (~Y6)
~SS_7: J9.6, U1.7 (~Y7)

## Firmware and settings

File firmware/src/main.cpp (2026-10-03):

/**
 * SPItFIRE - SPI Joystick and Mouse Adapter
 *
 * Dual joystick port test with manual type configuration.
 * Supports Delta 14B, Delta 3B Single, and Delta 3B Twin joysticks.
 */

#include <avr/io.h>
#include <avr/interrupt.h>
#include <util/delay.h>
#include "uart.hpp"
#include "adc.hpp"
#include "keypad.hpp"
#include "joystick.hpp"
#include "status_led.hpp"

namespace {
    constexpr uint16_t SAMPLE_DELAY_MS = 100;
    constexpr uint32_t BAUD_RATE = 115200;

    // Fire button pins (directly reading Acorn PB0/PB1)
    // Left fire (PB0): DA-15 pin 13 → PC6 (Port A) / PC7 (Port B)
    // Right fire (PB1): DA-15 pin 10 → PC4 (Port A) / PC5 (Port B)
    constexpr uint8_t FIRE_LEFT_A = PC6;
    constexpr uint8_t FIRE_LEFT_B = PC7;
    constexpr uint8_t FIRE_RIGHT_A = PC4;
    constexpr uint8_t FIRE_RIGHT_B = PC5;

    // Ground pins for 3BS/3BT button circuits
    // DA-15 pin 3 → PB2 (Port A) / PB3 (Port B)
    // DA-15 pin 6 → PC2 (Port A) / PC3 (Port B)
    constexpr uint8_t GND_PIN3_A = PB2;
    constexpr uint8_t GND_PIN3_B = PB3;
    constexpr uint8_t GND_PIN6_A = PC2;
    constexpr uint8_t GND_PIN6_B = PC3;

    // AGND_RIGHT for 3BT mode (right handset potentiometer ground)
    // DA-15 pin 5 → PB0 (Port A) / PB1 (Port B)
    constexpr uint8_t AGND_RIGHT_A = PB0;
    constexpr uint8_t AGND_RIGHT_B = PB1;

    void init_fire_buttons() {
        // Configure fire button pins as inputs with pull-ups
        DDRC &= ~(_BV(FIRE_LEFT_A) | _BV(FIRE_LEFT_B) | _BV(FIRE_RIGHT_A) | _BV(FIRE_RIGHT_B));
        PORTC |= _BV(FIRE_LEFT_A) | _BV(FIRE_LEFT_B) | _BV(FIRE_RIGHT_A) | _BV(FIRE_RIGHT_B);
    }

    // Y_RIGHT analog pins (shared with keypad ROW0)
    // PA6 (Port A) / PA7 (Port B) - need pull-ups disabled for 3BT analog
    constexpr uint8_t Y_RIGHT_A = PA6;
    constexpr uint8_t Y_RIGHT_B = PA7;

    // Configure ground pins for 3BS/3BT modes on a specific port
    void set_button_grounds(joystick::Port port, bool enable) {
        if (port == joystick::Port::PORT_A) {
            if (enable) {
                // Drive pins 3 and 6 low
                PORTB &= ~_BV(GND_PIN3_A);
                DDRB |= _BV(GND_PIN3_A);
                PORTC &= ~_BV(GND_PIN6_A);
                DDRC |= _BV(GND_PIN6_A);
            } else {
                // Release to input with pull-up (for keypad ROW1/COL1)
                DDRB &= ~_BV(GND_PIN3_A);
                PORTB &= ~_BV(GND_PIN3_A);  // No pull-up on COL1 (active-low strobe)
                DDRC &= ~_BV(GND_PIN6_A);
                PORTC |= _BV(GND_PIN6_A);   // Pull-up on ROW1
            }
        } else {
            if (enable) {
                PORTB &= ~_BV(GND_PIN3_B);
                DDRB |= _BV(GND_PIN3_B);
                PORTC &= ~_BV(GND_PIN6_B);
                DDRC |= _BV(GND_PIN6_B);
            } else {
                // Release to input with pull-up (for keypad ROW1/COL1)
                DDRB &= ~_BV(GND_PIN3_B);
                PORTB &= ~_BV(GND_PIN3_B);  // No pull-up on COL1 (active-low strobe)
                DDRC &= ~_BV(GND_PIN6_B);
                PORTC |= _BV(GND_PIN6_B);   // Pull-up on ROW1
            }
        }
    }

    // Configure PA6/PA7 for 3BT mode (disable pull-ups for analog input)
    // Also drive PB0/PB1 low to provide AGND_RIGHT for right handset pots
    void configure_3bt_analog(joystick::Port port, bool enable) {
        if (port == joystick::Port::PORT_A) {
            if (enable) {
                // Disable pull-up on PA6 for Y_RIGHT analog input
                PORTA &= ~_BV(Y_RIGHT_A);
                // Drive PB0 low to provide AGND_RIGHT (pin 5)
                PORTB &= ~_BV(AGND_RIGHT_A);
                DDRB |= _BV(AGND_RIGHT_A);
            } else {
                // Re-enable pull-up for keypad ROW0 (14B mode)
                PORTA |= _BV(Y_RIGHT_A);
                // Release PB0 to high-Z for keypad COL0 (no pull-up needed)
                DDRB &= ~_BV(AGND_RIGHT_A);
                PORTB &= ~_BV(AGND_RIGHT_A);
            }
        } else {
            if (enable) {
                // Disable pull-up on PA7 for Y_RIGHT analog input
                PORTA &= ~_BV(Y_RIGHT_B);
                // Drive PB1 low to provide AGND_RIGHT (pin 5)
                PORTB &= ~_BV(AGND_RIGHT_B);
                DDRB |= _BV(AGND_RIGHT_B);
            } else {
                // Re-enable pull-up for keypad ROW0 (14B mode)
                PORTA |= _BV(Y_RIGHT_B);
                // Release PB1 to high-Z for keypad COL0 (no pull-up needed)
                DDRB &= ~_BV(AGND_RIGHT_B);
                PORTB &= ~_BV(AGND_RIGHT_B);
            }
        }
    }

    // Read fire buttons for a port, returns 2 bits: bit0=left, bit1=right (1=pressed)
    // Buttons directly connected to row pins (active-low)
    uint8_t read_fire_buttons(joystick::Port port) {
        uint8_t result = 0;
        if (port == joystick::Port::PORT_A) {
            if (!(PINC & _BV(FIRE_LEFT_A))) result |= 0x01;
            if (!(PINC & _BV(FIRE_RIGHT_A))) result |= 0x02;
        } else {
            if (!(PINC & _BV(FIRE_LEFT_B))) result |= 0x01;
            if (!(PINC & _BV(FIRE_RIGHT_B))) result |= 0x02;
        }
        return result;
    }

    void print_menu() {
        uart::println("");
        uart::println("SPItFIRE Joystick Test");
        uart::println("----------------------");
        uart::print("Port A: ");
        uart::println(joystick::type_name(joystick::get_type(joystick::Port::PORT_A)));
        uart::print("Port B: ");
        uart::println(joystick::type_name(joystick::get_type(joystick::Port::PORT_B)));
        uart::println("");
        uart::println("Configure:");
        uart::println("  0-3: Port A (0=None, 1=3BT, 2=3BS, 3=14B)");
        uart::println("  4-7: Port B (4=None, 5=3BT, 6=3BS, 7=14B)");
        uart::println("");
    }

    void handle_command(uint8_t cmd) {
        joystick::Port port;
        joystick::Type type;

        if (cmd >= '0' && cmd <= '3') {
            port = joystick::Port::PORT_A;
            type = static_cast<joystick::Type>(cmd - '0');
        } else if (cmd >= '4' && cmd <= '7') {
            port = joystick::Port::PORT_B;
            type = static_cast<joystick::Type>(cmd - '4');
        } else {
            return;  // Invalid command, ignore
        }

        joystick::set_type(port, type);

        // Configure ground pins for button reading in 3BS/3BT modes
        bool needs_grounds = (type == joystick::Type::DELTA_3B_SINGLE ||
                              type == joystick::Type::DELTA_3B_TWIN);
        set_button_grounds(port, needs_grounds);

        // Configure PA6/PA7 for 3BT analog input (disable pull-ups from keypad::init)
        bool is_3bt = (type == joystick::Type::DELTA_3B_TWIN);
        configure_3bt_analog(port, is_3bt);

        // Print confirmation
        uart::print(port == joystick::Port::PORT_A ? "Port A: " : "Port B: ");
        uart::println(joystick::type_name(type));
    }

    void print_port_data(joystick::Port port) {
        joystick::Type type = joystick::get_type(port);

        // Print type code
        uart::print(joystick::type_code(type));
        uart::put(' ');

        if (type == joystick::Type::NO_JOYSTICK) {
            uart::print("----:----");
            return;
        }

        // Read analog axes
        uint16_t x = adc::read_x(port);
        uint16_t y = adc::read_y(port);

        uart::print_int_padded(x, 4);
        uart::put(':');
        uart::print_int_padded(y, 4);

        if (type == joystick::Type::DELTA_14B) {
            // Read keypad
            uint16_t buttons = keypad::scan(port);
            uart::print(" K:");
            uart::print_hex(static_cast<uint8_t>(buttons >> 8), 1);
            uart::print_hex(static_cast<uint8_t>(buttons & 0xFF), 2);
        }

        if (type == joystick::Type::DELTA_3B_TWIN) {
            // Read additional axes for twin joystick
            uint16_t x_r = adc::read_x_right(port);
            uint16_t y_r = adc::read_y_right(port);
            uart::print(" R:");
            uart::print_int_padded(x_r, 4);
            uart::put(':');
            uart::print_int_padded(y_r, 4);
        }

        if (type == joystick::Type::DELTA_3B_TWIN || type == joystick::Type::DELTA_3B_SINGLE) {
            // Read fire buttons (active-low: 0=pressed, 1=released)
            uint8_t buttons = read_fire_buttons(port);
            uart::print(" B:");
            uart::put((buttons & 0x01) ? 'L' : '-');  // Left fire
            uart::put((buttons & 0x02) ? 'R' : '-');  // Right fire
            // Debug: show raw PINC and PINB (ground pins)
            uart::print(" PC:");
            uart::print_hex(PINC, 2);
            uart::print(" PB:");
            uart::print_hex(PINB, 2);
        }
    }
}

int main() {
    // Initialize peripherals
    uart::init(BAUD_RATE);
    adc::init();
    keypad::init();
    joystick::init();
    init_fire_buttons();

    status_led::init();
    status_led::startup_flash();
    status_led::start_heartbeat();
    sei();

    // Print startup menu
    print_menu();

    while (true) {
        // Check for serial commands
        if (uart::available()) {
            uint8_t cmd = uart::get();
            handle_command(cmd);
        }

        // Print both ports on same line: A data | B data
        print_port_data(joystick::Port::PORT_A);
        uart::print(" | ");
        print_port_data(joystick::Port::PORT_B);
        uart::println("");

        _delay_ms(SAMPLE_DELAY_MS);
    }
}

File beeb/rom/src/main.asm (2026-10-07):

; SPItFIRE Sideways ROM
; Prototype: ROM header, service call dispatch, SPI core and the RTC
; module (OSWORD &0E read clock). See docs/rom-design.md.
;
; Build with beebasm from beeb/rom (see Makefile).

; OS calls
OSASCI = &FFE3
OSNEWL = &FFE7

; OS workspace
OSWORD_A   = &EF            ; OSWORD number, on service call &08
OSWORD_BLK = &F0            ; OSWORD parameter block address (2 bytes)
CMD_PTR    = &F2            ; Command line pointer, on service call &09

; Workspace &A8-&AF: free for *commands, but an OSWORD handler must
; save and restore it (rtc.asm does). Shared by the modules below.
ws = &A8

ORG &8000
GUARD &C000

.rom_start
    EQUB 0, 0, 0            ; No language entry
    JMP service
    EQUB &82                ; Service entry, 6502 code
    EQUB LO(copyright - rom_start)
    EQUB 1                  ; Binary version
.title
    EQUS "SPItFIRE"
    EQUB 0
.version
    EQUS "0.01"
.copyright
    EQUB 0
    EQUS "(C)2026 Robert Smallshire", 0

; ------ Service call dispatch ------
; A = reason, X = this ROM's slot, Y = parameter. Return A=0 to claim,
; otherwise A unchanged. X and Y must be preserved.
.service
    CMP #&08
    BEQ service_osword
    CMP #&09
    BEQ service_help
    RTS

; Service &08: unrecognised OSWORD
.service_osword
    PHA
    TXA
    PHA
    TYA
    PHA
    JSR rtc_osword          ; C=0 if claimed
    PLA
    TAY
    PLA
    TAX
    PLA
    BCS service_pass
    LDA #0
.service_pass
    RTS

; Service &09: *HELP. With no argument, print the title and version.
.service_help
    PHA
    TXA
    PHA
    TYA
    PHA
    LDA (CMD_PTR), Y
    CMP #13
    BNE help_done
    JSR OSNEWL
    LDX #0
.help_title
    LDA title, X
    BNE help_char
    LDA #' '                ; The zero between title and version
.help_char
    JSR OSASCI
    INX
    CPX #(copyright - title)
    BNE help_title
    JSR OSNEWL
.help_done
    PLA
    TAY
    PLA
    TAX
    PLA
    RTS

INCLUDE "src/spi.asm"
INCLUDE "src/rtc.asm"

.rom_end

SAVE rom_start, rom_end

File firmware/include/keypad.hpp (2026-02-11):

#ifndef SPITFIRE_KEYPAD_HPP
#define SPITFIRE_KEYPAD_HPP

#include <stdint.h>
#include "joystick.hpp"

namespace keypad {

/// Initialize keypad I/O pins for Delta 14B scanning
/// New pin mapping (Even=A, Odd=B):
/// - Columns: PB0/PB1 (COL0), PB2/PB3 (COL1), PC0/PC1 (COL2)
/// - Rows: PA6/PA7 (ROW0), PC2/PC3 (ROW1), PC4/PC5 (ROW2), PC6/PC7 (ROW3)
void init();

/// Scan keypad for a specific port and return 12-bit button state
/// Button numbering: switch_number = row * 3 + column (0-11)
/// Bit N = switch N, where 0 = pressed, 1 = not pressed
/// @param port Which joystick port to scan (PORT_A or PORT_B)
/// @return 12-bit button state in lower 12 bits of uint16_t
uint16_t scan(joystick::Port port);

/// Scan keypad and return raw column data for a specific port
/// @param port Which joystick port to scan
/// @param col0 Output: ROW3:ROW2:ROW1:ROW0 for column 0 (bits 3:2:1:0)
/// @param col1 Output: ROW3:ROW2:ROW1:ROW0 for column 1
/// @param col2 Output: ROW3:ROW2:ROW1:ROW0 for column 2
void scan_raw(joystick::Port port, uint8_t* col0, uint8_t* col1, uint8_t* col2);

}  // namespace keypad

#endif  // SPITFIRE_KEYPAD_HPP

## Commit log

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2026-01-01 Schematic capture of the Voltmace Delta 14b joystick internals
    [SPItFIRE.kicad_pcb, SPItFIRE.kicad_sch, voltmace-delta-14b.kicad_sch]
2026-01-02 Add UART and ADC drivers for joystick X-axis test
    Implements UART driver for serial debugging at 115200 baud (exact
    with 18.432 MHz crystal) and ADC driver for reading joystick position.
    Wiring notes for schematic capture:
    ATMega1284p connections:
    PA0 (pin 40) - ADC0 - Joystick X axis
    PA1 (pin 41) - ADC1 - Joystick Y axis (reserved)
    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
2026-01-02 Add Y-axis joystick reading and update wiring notes
    Reads both X and Y axes via ADC0 (PA0) and ADC1 (PA1).
    Updates documentation with corrected joystick wiring:
    Voltmace Delta 14b (DA-15):
    Pin 7 - Y pot wiper
    Pin 8 - AGND
    Pin 14 - VREF
    Pin 15 - X pot wiper
    ATMega1284p (DIP-40):
    PA0 (pin 40) - X axis
    PA1 (pin 39) - Y axis
    AVCC (pin 30) - VREF
    Also corrects load capacitor value to 15pF.
    [main.cpp]
2026-01-02 Add 3x4 keypad matrix driver for dual joysticks
    Implements column-strobe matrix scanning for Voltmace Delta 14b keypads.
    Supports two joysticks with shared column strobes.
    ATMega1284p pin assignments (DIP-40):
    PB0 (pin 1) - Column 0 strobe
    PB1 (pin 2) - Column 1 strobe
    PB2 (pin 3) - Column 2 strobe
    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
2026-01-02 Fix keypad matrix scanning for multi-button detection
    Use high-impedance columns instead of driving idle columns high.
    This prevents current paths through multiple pressed buttons in
    the same row from interfering with each other.
    Also increases settling time to 20us and adds recovery delay
    after each column scan for reliable pull-up restoration.
    [keypad.cpp]
2026-01-03 Voltmace pinouts
    [SPItFIRE.kicad_sch, voltmace-delta-14b.kicad_sch, voltmace-delta-3b-single.kicad_sch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]
2026-02-11 Update schematic naming convention to keep Kicad happy
    [voltmace-delta-14b.kicad_sch, voltmace-delta-3b-single.kicad_sch, voltmace-delta-3b-twin.kicad_sch]
2026-02-11 Add dual joystick port support with automatic type detection
    Implements passive detection algorithm to identify Delta 14B, Delta 3B
    Single, Delta 3B Twin, or no joystick connected. Detection uses
    variance-based stability measurement (8 samples over 24ms) to
    distinguish floating pins from connected pots, avoiding false readings
    from mains hum.
    State machine requires 3 consistent detections before confirming type
    change, and all transitions must go through NO_JOYSTICK state.
    Pin mapping uses interleaved scheme: even AVR pins for Port A, odd
    for Port B. Keypad driver rewritten for new column/row assignments.
    [adc.hpp, keypad.cpp, keypad.hpp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]
2026-03-07 Replace auto-detection with manual joystick type configuration
    Auto-detection proved unreliable due to capacitive coupling between
    adjacent analog pins. Manual configuration via serial commands (0-7)
    is simpler and completely reliable.
    Add fire button support for 3BS and 3BT modes. These joysticks expect
    DA-15 pins 3 and 6 to be grounded (as on BBC Micro), so the firmware
    now drives PB2/PC2 (Port A) or PB3/PC3 (Port B) low when these modes
    are selected. Fire buttons read via PC4/PC6 (Port A) or PC5/PC7 (Port B).
    Add UART receive functions for serial command input.
    Document button wiring for all joystick types.
    [main.cpp]
2026-03-07 Add AGND_RIGHT support for Delta 3B Twin right handset
    The Delta 3B Twin uses DA-15 pin 5 as analog ground for the right
    handset's potentiometers (AGND_RIGHT), separate from pin 8 which
    grounds the left handset. On SPItFIRE, pin 5 maps to PB0/PB1.
    When 3BT mode is selected, drive PB0 (Port A) or PB1 (Port B) low
    to provide the ground reference. Also disable the pull-up on PA6/PA7
    (Y_RIGHT) that keypad::init() enables for ROW0.
    Without this fix, the right handset's X and Y axes read ~1023 as the
    potentiometer wipers have no ground reference.
    [main.cpp]
2026-03-07 Restore pull-ups when switching from 3BT to 14B mode
    When switching joystick type from 3BT to 14B, the pins used as ground
    outputs for 3BT button circuits must be properly restored for keypad
    scanning:
    - PC2/PC3 (ROW1): re-enable pull-up for row input
    - PB0/PB1 (COL0): release to high-Z for column strobe
    - PB2/PB3 (COL1): release to high-Z for column strobe
    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
2026-03-07 Add Time&Config as alternative VIA serial approach
    Document the Time&Config project's different approach to VIA serial
    communication for reference. Key differences: external RTC-provided
    clock on CB1, no PB1-CB1 wiring, different chip select lines (PB5/PB7).
    Also fix typo in series resistor section.
2026-03-07 Document as-built SPI wiring with corrected resistor placement
    - MOSI and SCK have 1k resistors for ISP programmer override
    - MISO has 1k resistor for protection
    - SS is direct (ISP uses RESET, not SS)
    - Added wiring table for female DE-9 breakout to AVR
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2026-03-14 SPI soak test with XOR verification and counters
    BBC side sends incrementing bytes, AVR returns each XOR'd with &55.
    Display shows sent, expected, received, plus 16-bit good/bad counters.
    Key fixes from debugging:
    - AVR uses SPI Mode 1 (CPHA=1) to match 6522 shift register timing
    - Tight polling loop on AVR (no heartbeat) for reliable response
    - Two transfers per test: first sends data, second gets response
    - Bit-bang with SR mode 0 captures MISO on falling CB1 edge
    [spi_slave.cpp, spitest.asm]
2026-03-15 Fix VIA initialization to use absolute register values
    The alternating pass/fail behavior was caused by init_via using
    AND/OR operations that preserved stale bits in PCR and ACR registers.
    Now explicitly sets PCR=0 and ACR=0 for a known initial state.
    Also adds:
    - SPIPERF: Performance test (65536 transfers with timing)
    - SPI256: Minimal 256-byte timing test for debugging
    - SCK now idles LOW to match AVR SPI Mode 1 (CPOL=0)
    [spi256.asm, spiperf.asm, spitest.asm]
2026-03-15 Fix SPI speed by disabling CB1 interrupts
    The OS leaves CB1 interrupts enabled, and since CB1 is wired to SCK,
    every clock falling edge triggered an IRQ. This caused 2048 interrupts
    per 256-byte transfer, reducing speed from ~4200 bytes/sec to ~6 bytes/sec.
    Fix: Write %00011000 to IER at start of init_via to disable CB1/CB2
    interrupts before any SPI operations.
    Also:
    - Change AVR to SPI Mode 0 (CPOL=0, CPHA=0) to match BBC timing
    - Add SPI256 minimal timing test to Makefile
    - Document VIA initialization requirements in spi-interface.md
    [spi256.asm, spi_slave.cpp, spiperf.asm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]
2026-03-15 Fix SPIPERF division algorithm
    The 24-bit / 16-bit division was producing results 256x too large
    because the dividend storage (div_tmp+0:+2) overlapped with the
    remainder comparison region (div_tmp+2:+3).
    Fix: Use 5-byte workspace with separate regions:
    - div_tmp+0:+2 = dividend (24-bit)
    - div_tmp+3:+4 = remainder (16-bit)
    Also add version number to output for easier debugging.
    [spiperf.asm]
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2026-03-21 Document SPI transfer modes with code and benchmarks
    Added complete code examples for bit-bang and turbo read modes.
    Corrected shift register mode (mode 3, not mode 2). Added measured
    performance data: bit-bang 4124 bytes/sec, turbo 7371 bytes/sec (79%
    faster). Updated clock speed section with actual throughput figures.
2026-03-21 Update SPI interface docs for 74HC138 decoder
    Replaced direct SS line design with 74HC138 3-to-8 decoder, expanding
    from 3 to 7 SPI device slots. Updated all wiring diagrams, device
    selection tables, and initialization code. Y1 assigned to SPItFIRE,
    Y2-Y7 unassigned for future expansion.
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2026-04-05 The bulk of the schematic layout for the board (pending review and check)
    [SPItFIRE.kicad_sch, main.kicad_sch, voltmace-delta-14b.kicad_sch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]
2026-04-19 Fix PCINT vector for Port D and add runtime mode switching
    Port D on ATMega1284P uses PCINT24-31 (PCINT3 group), not PCINT16-23
    (PCINT2) as previously assumed. Fixed to use PCMSK3/PCIE3/PCINT3_vect.
    Also fixed quadrature decode table column ordering (numerical order,
    not Gray code order).
    Added SPI commands 0xF1/0xF2/0xF3 for runtime pinout switching
    between AMX, Amiga, and Atari mice. BBC test program SPIMOUSE now
    supports pressing 1/2/3 to switch modes, displays current mode,
    and shows buttons in L M R order.
    Tested with AMX mouse on prototype hardware - quadrature decoding
    working correctly on both axes.
    [mouse.cpp, spimouse.asm]
2026-04-20 Fix Amiga mouse Y-axis pin assignment (YA/YB were swapped)
    DE-9 Pin 1 is YB (not YA) and Pin 3 is YA (not YB) for the Amiga
    mouse. Verified with actual Amiga mouse hardware - Y axis was
    reversed before this fix. Corrected in pinout tables, remap table
    generator, and firmware mode switching.
    [mouse.cpp]
2026-04-25 Document MDFS Y-axis label convention difference
    The Amiga/Atari pinouts on mdfs.net reverse the Y-axis signal
    labels (YA/YB) relative to native conventions, to match BBC Micro
    coordinate system handedness. Our pinout table uses native Amiga/
    Atari conventions. This note prevents future confusion when
    cross-referencing MDFS as a source.
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2026-04-25 Schematic updates
    [main.kicad_sch]
2026-04-25 Schematic updates and rule checking
    [main.kicad_sch, voltmace-delta-14b.kicad_sch, voltmace-delta-3b-single.kicad_sch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]
2026-04-27 ERC warnings and labels
    [voltmace-delta-14b.kicad_sch, voltmace-delta-3b-single.kicad_sch, voltmace-delta-3b-twin.kicad_sch]
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2026-06-23 Work on the schematic and the beginnings of footprint assignment
    [SPItFIRE.kicad_pcb, main.kicad_sch, voltmace-delta-14b.kicad_sch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]
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2026-07-30 Work in progress on layout and routing
    [SPItFIRE.kicad_pcb, main.kicad_sch]
2026-09-04 Completed layout and routing. Now need to work through the few DRC errors
    [SPItFIRE.kicad_pcb, main.kicad_sch]
2026-09-05 Completed layout and passes DRC check
    [SPItFIRE.kicad_pcb]
2026-09-05 Replaced footprint for small crystal ballast capacitors
    [SPItFIRE.kicad_pcb]
2026-09-24 Added BoM
    [SPItFIRE.csv, main.kicad_sch]
2026-10-03 Drive Rev 1 status LED active-high with a heartbeat
    The Rev 1 PCB wires the status LED active-high (PD7 -> R2 -> D2 -> GND),
    the opposite of the breadboard prototype, so the LED stayed lit after
    startup. Status LED handling is now a shared status_led module used by
    all three firmware targets: three quick flashes on reset, then a
    once-per-second double-flash heartbeat driven by a Timer0 compare
    interrupt at exactly 100 Hz, independent of SPI traffic.
    The per-byte SPI activity toggles are removed as they would scramble
    the heartbeat pattern.
    [main.cpp, mouse.cpp, spi_slave.cpp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]
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2026-10-03 Record mirrored J13 footprint erratum in Rev 1 bring-up log
    The custom male DE-9 footprint used for the Peripheral port has the
    same pad coordinates as the female footprint, so J13 is mirrored on Rev 1
    and +5V/GND appear on pins 8/7. Documents the effect, the warning against
    plugging in mice directly, the mirroring adapter workaround, and starts
    a Rev 2 errata table.
2026-10-04 Record reverse-side J13 mounting as the Rev 1 mirroring workaround
    Fitting the right-angle male DE-9 on the solder side mirrors it relative
    to the footprint and cancels the footprint error. Verified power pins and
    serial transmit/receive directly through the re-mounted connector.
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2026-10-05 Add SPISETTIME program to set the DS3234 RTC
    Prompts for the date and time, validates them (including leap years),
    computes the day of the week, waits for a key press so the clock starts
    on an exact second, burst-writes the time registers and clears the
    oscillator stop flag. Verified on the Rev 1 board.
    [spisettime.asm]
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2026-10-05 PCB silkscreen updates towards Rev 2
    [SPItFIRE.kicad_pcb]
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2026-10-07 Add TIMEPROBE, a probe of OSWORD &0E on the Master Compact
    Shows what OSWORD &0E (read clock) returns and who answers it: with all
    ROMs, with every ROM hidden (MOS only), and with each ROM on its own.
    ROMs are hidden by zeroing their entries in the MOS ROM type table,
    restored straight after each call. Also converts fixed BCD blocks with
    subcall 2 and reads the ANFS file server subcalls 3 and 4.
    On the Compact (MOS 5.10, ANFS 4.25 in slot 3) it showed that ANFS is the
    only ROM answering subcalls 0 and 1, that with no ROM the MOS returns
    Fri,31 Dec 1999.23:59:59, and that the MOS's subcall 2 always prints the
    century as 19.
2026-10-07 Redesign the RTC module around OSWORD &0E/&0F
    Replace the sketch of *SETTIME/*SETDATE commands and writing the RTC
    into the system clock with the standard clock interface: answer OSWORD
    &0E (read) and &0F (write) through service call &08, so *TIME, TIME$ and
    other programs see the DS3234.
    Record what TIMEPROBE found on the Compact: MOS 5.10 offers OSWORD &0E
    to ROMs, returns a fixed 31 Dec 1999 default otherwise, and always
    prints the century as 19 in subcall 2; ANFS 4.25 answers subcalls 0 and
    1 from the file server and mis-decodes dates after 1996. List the calls
    to implement and leave alone, the conventions from the Stardot
    discussions, and move the RTC module to the front of the plan.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
2026-10-07 Add the SPItFIRE ROM prototype with OSWORD &0E clock reading
    The first code of the SPItFIRE Sideways ROM: header, service call
    dispatch, *HELP, a mode 3 SPI core, and the RTC module. The RTC module
    answers OSWORD &0E subcalls 0 and 1 from the DS3234 through service call
    &08, building the subcall 0 string with the real century. Subcall 2 is
    claimed experimentally, to find out whether MOS 5.10 offers it to ROMs.
    Other subcalls, and reads while the oscillator stop flag is set, are
    passed on. &A8-&AF are saved and restored, and no errors are raised.
    The SPI set-up changes only the shift register bits of ACR and the CB
    bits of PCR, leaving the printer port and timers alone.
    The Makefile builds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
    [main.asm, rtc.asm, spi.asm]
2026-10-07 Confirm that MOS 5.10 offers OSWORD &0E,2 to ROMs
    TIMEPROBE now also converts a BCD block with subcall 2 with all ROMs
    present. With the SPItFIRE ROM loaded it gives 2026 for year &26, where
    the MOS on its own gives 1926: the MOS offers subcall 2 to ROMs before
    converting it itself, so the ROM's subcall 2 handler fixes the century
    for every caller. Update the ROM comments and the design doc to match.
    [rtc.asm]
2026-10-07 Set the DS3234 through OSWORD &0F
    Handle OSWORD &0F lengths 8 ("hh:mm:ss"), 15 ("Ddd,dd Mon yyyy") and 24
    (both), so *TIME <string> and TIME$= set the RTC. Fields are read at
    fixed positions; the weekday name is ignored and the weekday computed
    from the date with Sakamoto's method, reduced to 8 bits for 2000-2199.
    Years outside 2000-2199, out-of-range fields, non-digits and dates past
    the end of the month are passed on. A successful write clears the
    oscillator stop flag.
    Checked on a 6502 emulator with a DS3234 model against Python's
    calendar for 9,741 dates, and on the Master Compact, where TIME$= and
    *TIME set the time, the date or both.
    [rtc.asm]
2026-10-08 Record the Compact's PB2-PB4 idle levels and the Rev 2 decision
    Measured with SPItFIRE attached: with port B released (as after reset)
    the Compact pulls A0-A2 up through about 4.1k each, so the 74HC138
    selects Y7 (J9 pin 6 low). Ctrl-BREAK and power-on leave the lines high;
    only SPItFIRE code (e.g. *TIME) drives them, to Y0.
    Pull-downs strong enough to keep Y0 as the idle code would need about
    1.5k, more than the VIA's NMOS outputs can drive high. Make Y7 "no
    device" for Rev 2 instead: leave Y7 unconnected, move J9 to Y0, and
    optionally add weak pull-ups; the software "no device" code becomes
    %00011100.
2026-10-08 Make Y7 the "no device" decoder code
    The Compact pulls PB2-PB4 high (about 4.1k each) whenever port B is not
    driving them, so the 74HC138 rests on Y7 at power-up, after reset and
    before any SPItFIRE code runs. Deselect to the same code everywhere, so
    the bus looks the same whether or not SPItFIRE code has run. Y0 cannot
    serve instead: pull-downs strong enough to beat the Compact's pull-ups
    would be more than the VIA's outputs can drive high.
    - Test programs: deselect by setting the select bits rather than
    clearing them, and start on Y7. SPIPERF and SPITPERF reselected the
    AVR in their resync by ORing its code into the deselected value, which
    only worked while "no device" was zero; cle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
    [spi.asm, spi256.asm, spimouse.asm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]
2026-10-08 Add an emulator regression test for the ROM's RTC module
    beeb/rom/test/test_rtc.py assembles the ROM and runs its OSWORD &0E/&0F
    handler on py65, against a model DS3234 that decodes the bit-banged SPI
    from the User VIA port B writes, so the parsing, weekday arithmetic, BCD
    formatting and SPI code all run. It checks:
    - set and read-back, and partial (time-only, date-only) writes;
    - the weekday for a sample of 9,741 dates in 2000-2199 against Python's
    calendar, including the century bit and 2100 not being a leap year;
    - invalid data, calls the ROM must leave alone, subcall 2 conversion;
    - passing on when the oscillator has stopped, a field is out of range,
    or no DS3234 is fitted (MISO hig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
2026-10-11 Plot Delta joysticks in screen orientation in SPIJOY
    Acorn joysticks read X high at the left, the opposite of screen X, so
    SPIJOY flips X when it plots a Delta's position. The Bitstik reads low
    at the left and at the front, so only its Y is flipped. Per-type tables
    select the flips; the printed values stay raw. Record both polarities
    in the bring-up log and the ROM design.
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2026-10-11 Provide ADVAL from SPItFIRE through MOS 5.x service call &2C
    The ROM's new joystick module hands the Master Compact's joystick
    handling to service call &2C at reset (*FX190,128,127). Every second
    centisecond it reads a new JOY_ADVAL burst from the spijoy firmware: a
    status byte and the five ADVAL workspace bytes, which the AVR builds
    with 16-bit scaling and direction bits, so the 6502 only stores them.
    The poll runs only when no device is selected and restores the VIA
    state, so it cannot disturb MMFS or the RTC module, and it sets the
    port type itself if the AVR has reset.
    Add an emulator test with a model AVR, and document the call, the
    burst and the first result: a Delta 3B Twin on Port A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
2026-10-13 Add *SPITFIRE and *HELP SPITFIRE commands to the ROM
    *SPITFIRE prints the version and modules. *SPITFIRE JOYSTICK reports
    whether the MOS's joystick handling is delegated to the ROM, and
    *SPITFIRE JOYSTICK ON|OFF sets or clears bit 7 of the joystick byte
    (*FX190) while keeping its other bits. Anything else after the
    JOYSTICK keyword is a syntax error.
    *HELP lists the SPITFIRE topic, and *HELP SPITFIRE [JOYSTICK] lists
    the commands. Both end with the current joystick setting, the way the
    network filing systems report their station number. *HELP JOYSTICK is
    left to other ROMs.
    test_commands.py runs service calls &04 and &09 on py65 and checks the
    output, the OSBYTE &BE calls and the errors.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
2026-10-13 Keep the joystick configuration in the AVR's EEPROM
    The spijoy firmware saves both port types and the handset that the MOS
    joystick reads in a checksummed EEPROM record, and applies them at
    power-up. A blank or corrupt record gives both ports 3B Twin and
    handset 0. New commands: JOY_MOS (0x54) bursts the configured handset,
    JOY_CONFIG (0x58) returns the configuration in one byte, and CFG_TYPE_A,
    CFG_TYPE_B and CFG_HANDSET (0xD0-0xDB) set and save a value. Only the
    CFG_ commands write the EEPROM, from the main loop, and only bytes that
    change are rewritten. JOY_TYPE_ stays unsaved, so SPIJOY leaves the
    configuration alone.
    The ROM's poll reads JOY_MOS and no longer forces Port A to 3B Twin.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
2026-10-24 Design the joystick presets and ADVAL channel map, and document mouse conventions
    rom-design.md gains the joystick design: BBC, Delta 14B/1 and four-player
    presets, joysticks 3 and 4 at ADVAL(16)-(20) (the 1-4 layout 16 channels
    up), and Delta 14B keypads at ADVAL(10)/(11) and (26)/(27). The mouse
    section is corrected (AMX's INKEY-107 to -109) and covers compatibility
    with the Master Compact's PMFS driver.
    adval-and-mouse-conventions.md collects OSBYTE &80's behaviour across MOS
    versions, known ADVAL channel uses, the JGH and AMX mouse interfaces, and
    a description of PMFS from the Compact's Welcome disc.
2026-10-24 List the Rev 1 PCB errata and the changes planned for Rev 2
    Required: mirror the J13 male DE-9 footprint, pull MISO up, and make Y7
    "no device" by moving J9 to Y0. Optional: weak pull-ups on A0-A2,
    protecting the 5V rail from the USBasp, supply margin, and the BOD and
    EESAVE fuses. Also lists what Rev 1 has not yet verified.
    CLAUDE.md points to the errata and the ADVAL and mouse conventions.
2026-10-24 Add the 0201 crystal load capacitors and footprint tidy-ups to the Rev 1 errata
    C2 and C6 move to 0603 hand-solder footprints like the other passives,
    with the proven 15 pF value set. C3's LED footprint and the resistors'
    capacitor footprints are listed as optional tidy-ups.
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2026-10-24 Correct where the Rev 1 mounting holes H305-H308 are
2026-10-25 Corrects the pin ordering of the DE9 Male footprint by mirroring
2026-10-25 Corrects the pin 1 marker on the DE-9 Male connector
2026-10-25 Adds a note about missing ground pours in Rev 1
2026-10-25 Corrects the routing around the new corrected peripheral DE-9 connector
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2026-10-25 Crystal load capacitors C2 and C6 are 0201 instead of 0603 and were missing their 27 pF values in the schematic
2026-10-25 Fixed the footprint of C3
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2026-11-09 Record Rev 2 peripheral, mouse and joystick bring-up
    J13 power pins and serial, the flux residue that broke the SPI bus, Amiga
    and Atari mice on J13, the AMX mouse on J14, and the joystick ports,
    including the PB0-GND bridge at TQFP pins 39-40 that broke Port A's
    keypad column.
2026-11-10 Replace joystick presets with port types and slot allocation
    Each port declares what is plugged into it, and joysticks are numbered by
    filling ADVAL(1)-(4) then ADVAL(17)-(20) from Port A onwards. One fire bit
    per joystick, and keypads by joystick number. Replaces the presets,
    SETTYPE and USE, and records that the joystick channels clear PMFS's.
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2026-11-10 Allocate joysticks to ADVAL slots in the ROM
    The poll reads the JOY_ALL burst: ADVAL(0)-(2) go to the MOS's workspace
    and the rest to one page of private HAZEL workspace, claimed through
    service calls &24/&22 and marked with a signature. A BYTEV hook,
    installed through the extended vector, answers channels 3, 4, 10, 11,
    16-20, 26 and 27 and passes everything else on. *SPITFIRE JOYSTICK PORT
    replaces SETTYPE and USE; *SPITFIRE ADVAL, *STATUS and OSWORD &3F are
    new, and without workspace the joystick commands ask for Ctrl-Break.
    Tested on the emulator against a model of the firmware, and on the
    Compact.
2026-11-10 Raise ADC conversion events and step the channel in the poll
    The hand-over to service call &2C skips the end of the MOS's joystick
    routine, which raises event 3 every centisecond and steps the current
    ADC channel that ADVAL(0) returns in its high byte. The poll now does
    both, so *FX16, *FX17 and software waiting for a conversion behave as
    without the ROM. Tested on the Compact: the channel cycles, and 101
    events arrive in one second.
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

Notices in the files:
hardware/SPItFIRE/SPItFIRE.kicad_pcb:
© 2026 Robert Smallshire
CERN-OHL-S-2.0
